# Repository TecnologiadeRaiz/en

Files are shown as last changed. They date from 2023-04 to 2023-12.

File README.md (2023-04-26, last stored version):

# This project is documented with GitBuilding

## What is GitBuilding

GitBuilding is an OpenSource project for documenting hardware projects with minimal
effort, so you can stop writing and GitBuilding. GitBuilding is a python program that
works on Windows, Linux, and MacOS. More information on the GitBuilding project, or how
to install GitBuilding please see the [GitBuilding website](http://gitbuilding.io)

## How do I edit the documentation?

To edit the documentation you do not need to install anything, but you will need to
install something to build the final version of the documentation (such as a website).
The documentation files can be opened in a plain text editor such as Windows Notepad,
Notepad++, gedit, VS Code, etc. GitBuilding also comes with a browser-based editor that
displays has a live display of the final HTML documentation.

If you have ever used [markdown](https://www.markdownguide.org/basic-syntax/) you will
notice that the files you are editing are markdown files. GitBuilding uses an extended
markdown syntax (that we call BuildUp). This allows you to keep track of parts in the
documentation. More detail on the documentation is available on the
[GitBuilding website](https://gitbuilding.io/syntax/). There is also additional
[syntax for configuration](https://gitbuilding.io/syntax/buildconfsyntax), and for
[part libraries](https://gitbuilding.io/syntax/builduplibrary/).

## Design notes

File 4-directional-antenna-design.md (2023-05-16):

<!--
SPDX-FileCopyrightText: 2023 Tecnología de Raíz <tecnologiaderaiz@disroot.org>

SPDX-License-Identifier: CC-BY-NC-4.0
-->

# Directional antenna design

The present design aims to provide how to make a directional MiMo antenna for 5Ghz, capable of achieving a gain of 20dB to 25dB.

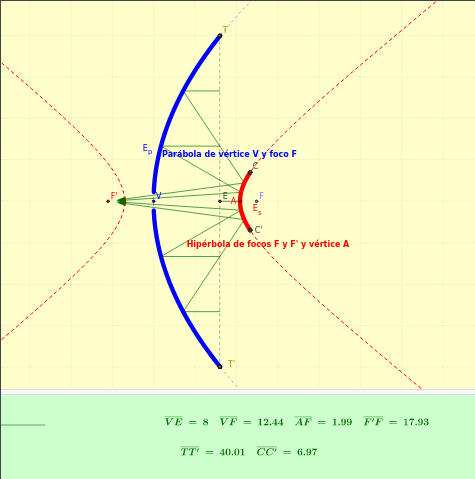
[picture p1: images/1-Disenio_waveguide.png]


In this new iteration of the "Trompebolic" design, we used a 44mm waveguide with a reflector to illuminate the parabolic dish.
We used a 40cm diameter and 8cm high parabolic dish as a mould, calculating the focus at 12.5cm from the centre.

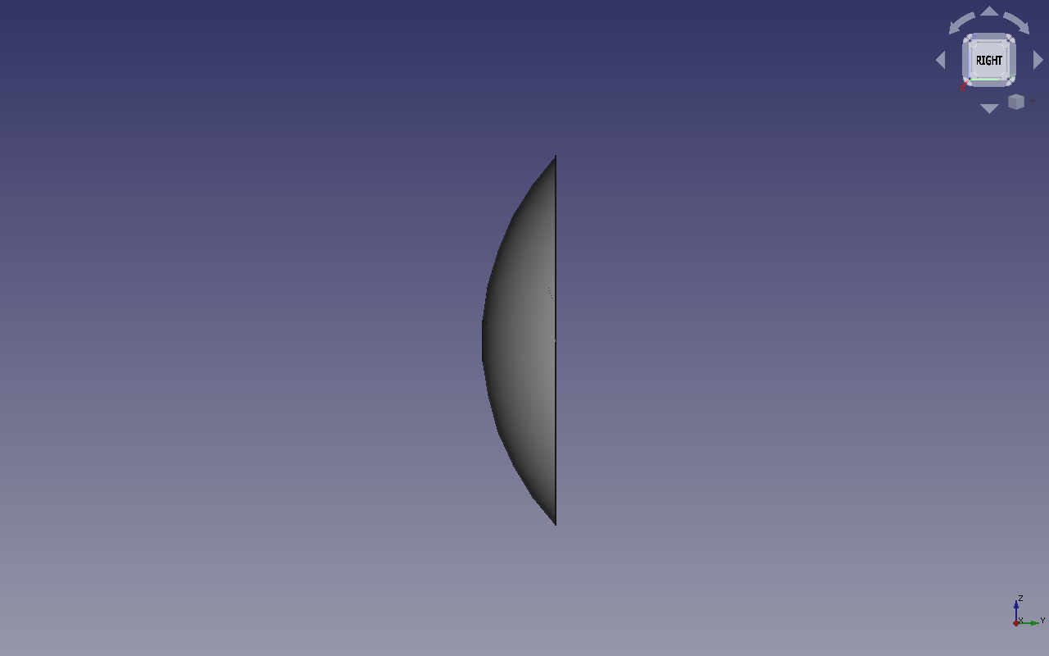
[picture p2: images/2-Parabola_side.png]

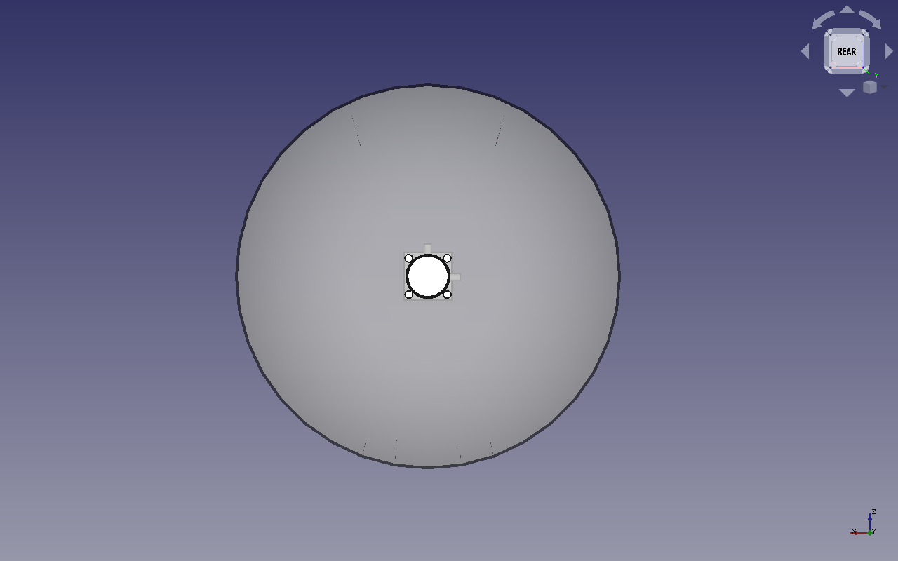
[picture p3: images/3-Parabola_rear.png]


### Reflector.

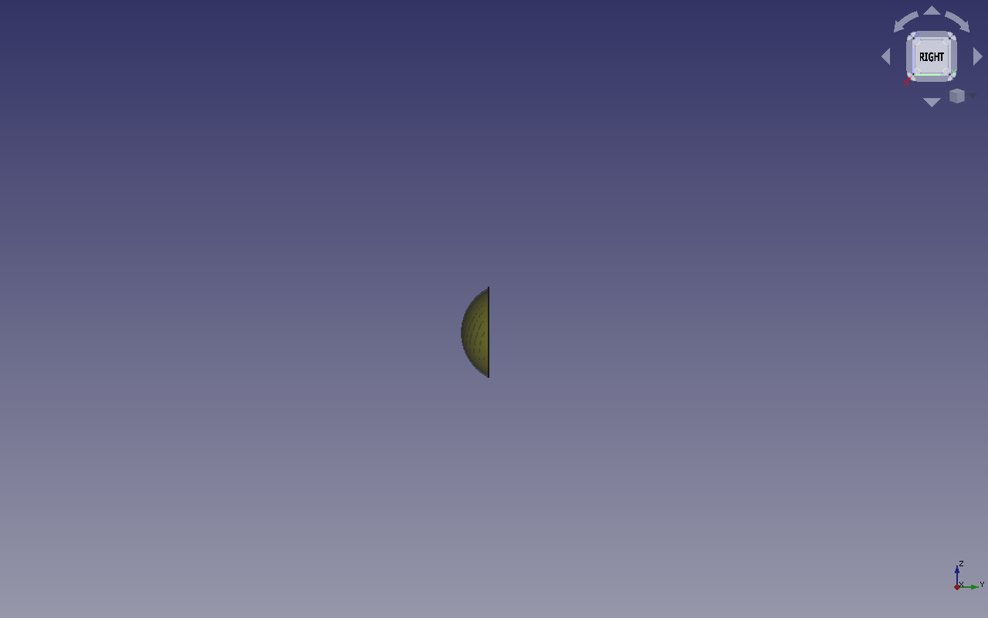
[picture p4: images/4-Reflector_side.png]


### Parabola support and handles.

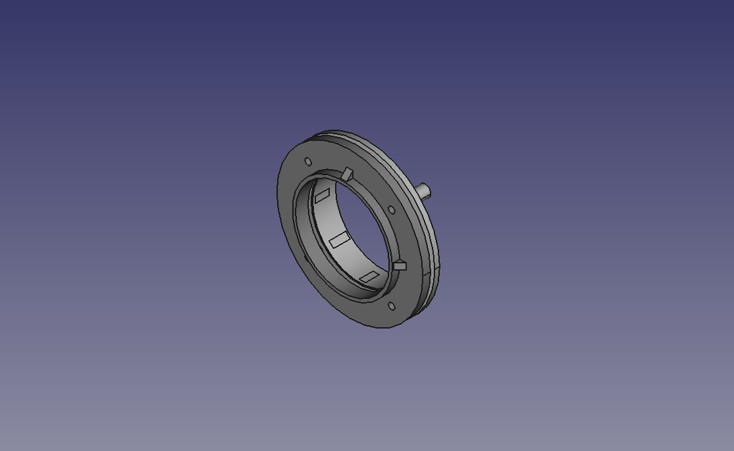
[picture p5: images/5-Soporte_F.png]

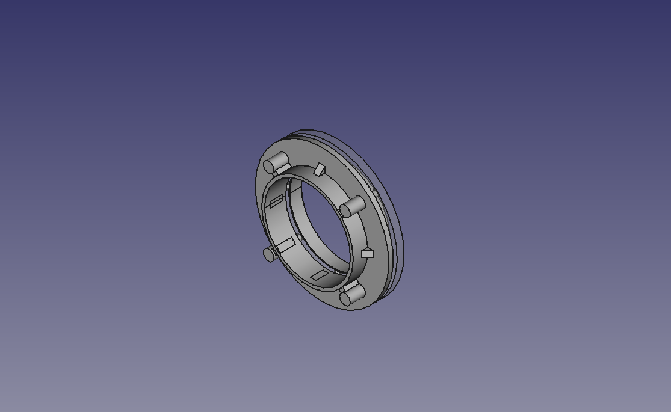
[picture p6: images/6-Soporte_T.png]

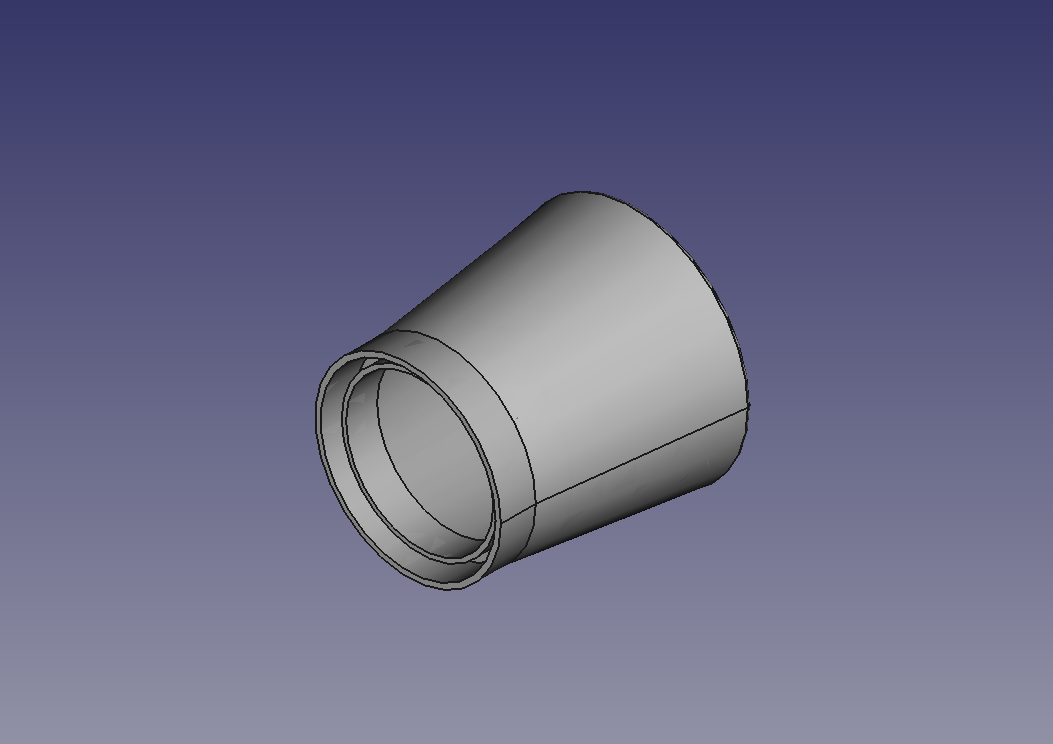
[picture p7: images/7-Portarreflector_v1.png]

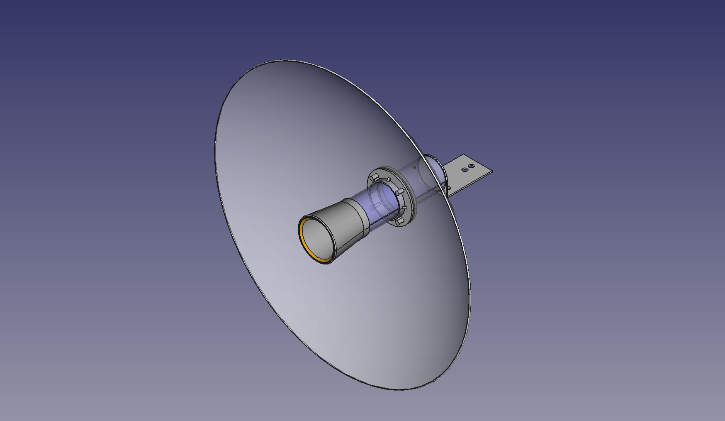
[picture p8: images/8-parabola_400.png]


### Final design.

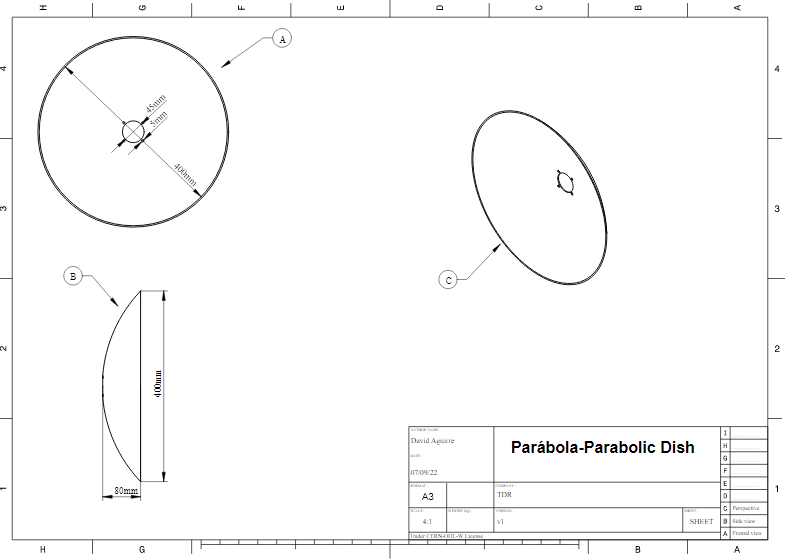
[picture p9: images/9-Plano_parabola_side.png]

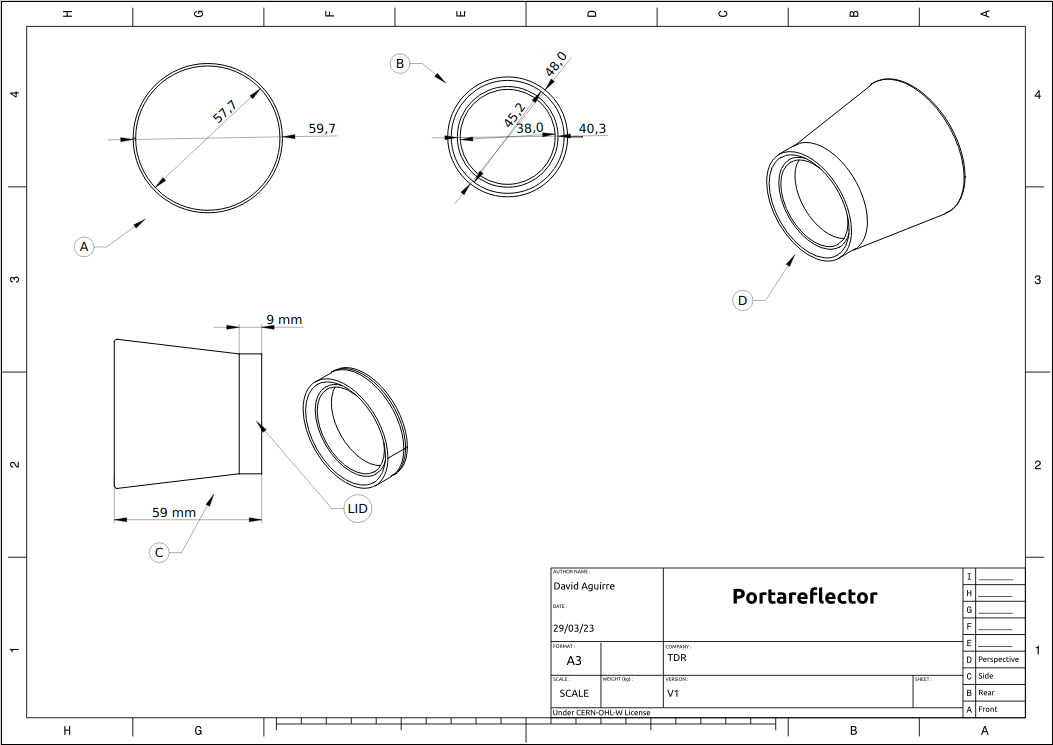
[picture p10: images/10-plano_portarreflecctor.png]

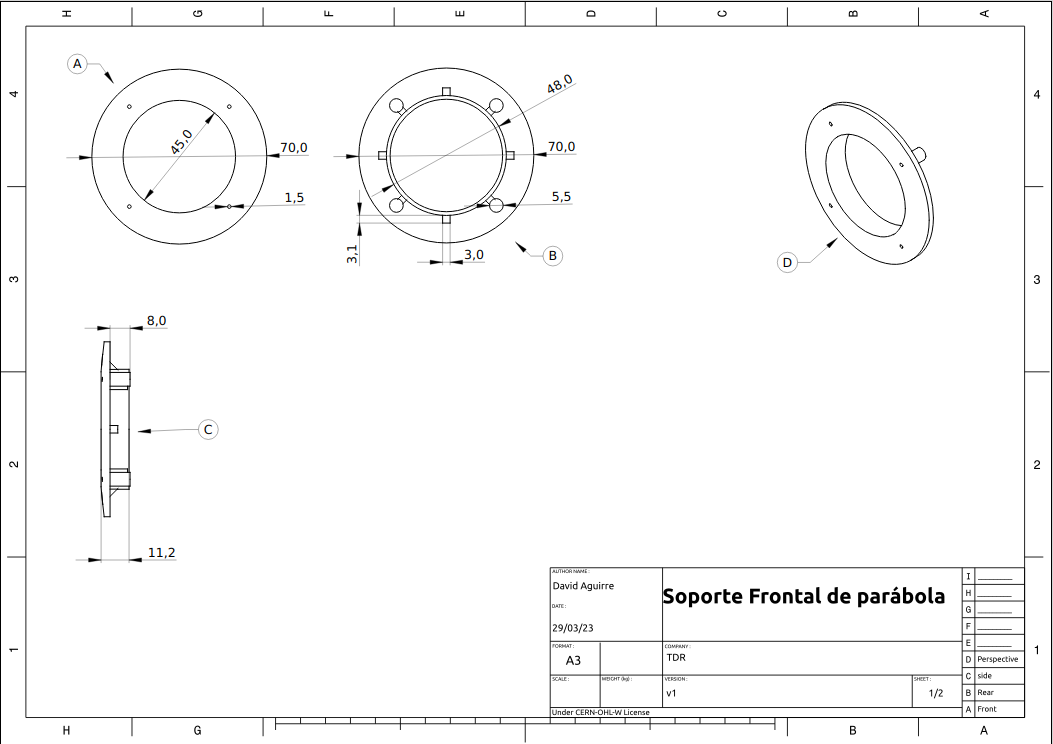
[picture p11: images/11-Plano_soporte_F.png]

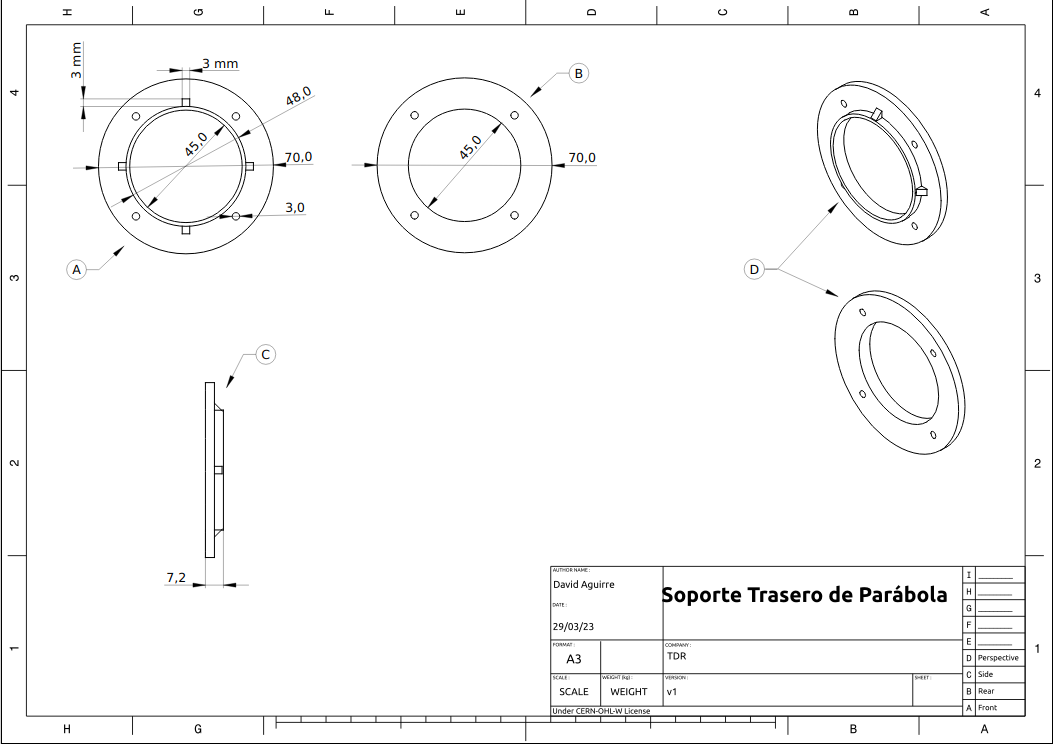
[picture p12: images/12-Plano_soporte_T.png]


___

Logo NLnet: abstract logo of four people seen from above

<p>This project was funded through the <strong> <a href="https://nlnet.nl/useroperated/">User-Operated Internet</a> </strong> fund, a fund established by <a href="https://nlnet.nl">NLnet</a> made possible by financial support from the <a href="https://pkt.cash" rel="nofollow">PKT Community</a> <a href="https://pkt.cash/network-steward" rel="nofollow">The Network Steward</a> and stichting <a href="https://technologycommons.org">Technology Commons Trust</a>.</p> 

<p>En cooperación con <a href="https://altermundi.net/">AlterMundi.</a></p>

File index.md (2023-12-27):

<!--
SPDX-FileCopyrightText: 2023 Tecnología de Raíz <tecnologiaderaiz@disroot.org>

SPDX-License-Identifier: CC-BY-NC-4.0
-->

# Tecnología De Raíz

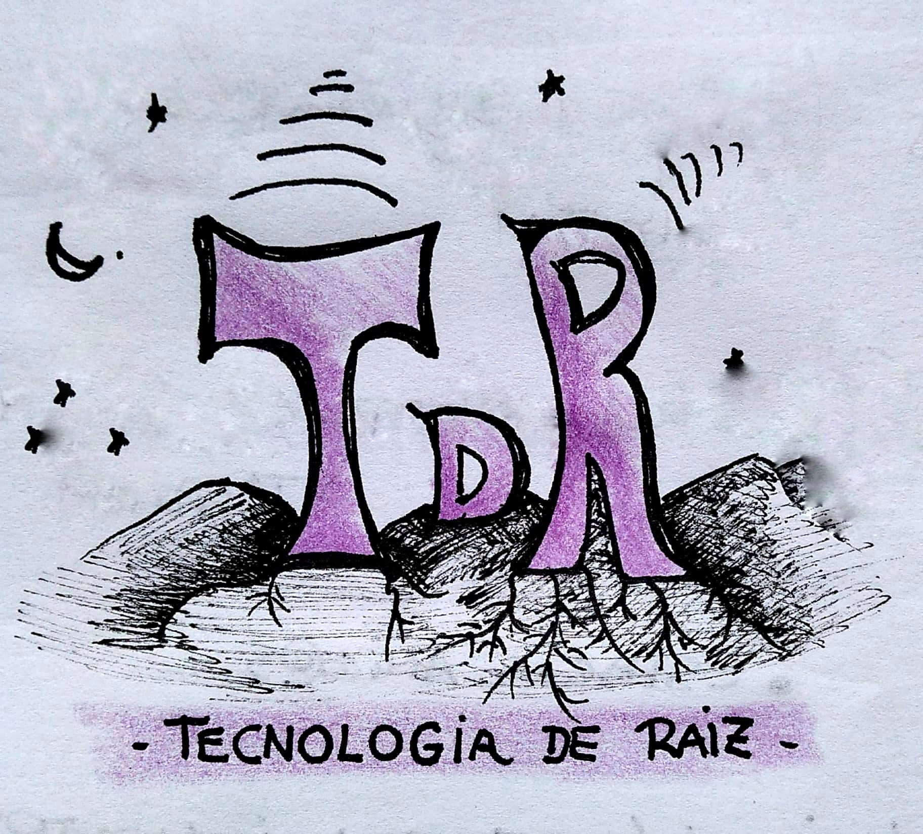
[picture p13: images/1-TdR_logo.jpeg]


## We are TdR

Neighbors of the Ecological Neighborhood "El Montecito" located in Punilla Valley (Córdoba, Argentina)

We formed a study and research group, wherein we created a space to work and study together, and we have sustained it continuously since mid-2019.

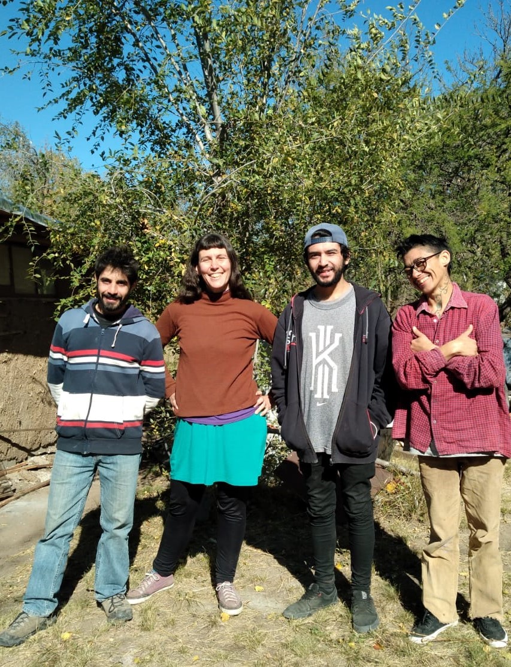
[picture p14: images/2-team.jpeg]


We start from curiosity and interest in sharing information about electricity, electronics, technology and the right to repairs. 
Going that way, the MonteNet network was simultaneously deployed in our neighborhood, and we began to learn about community networks.

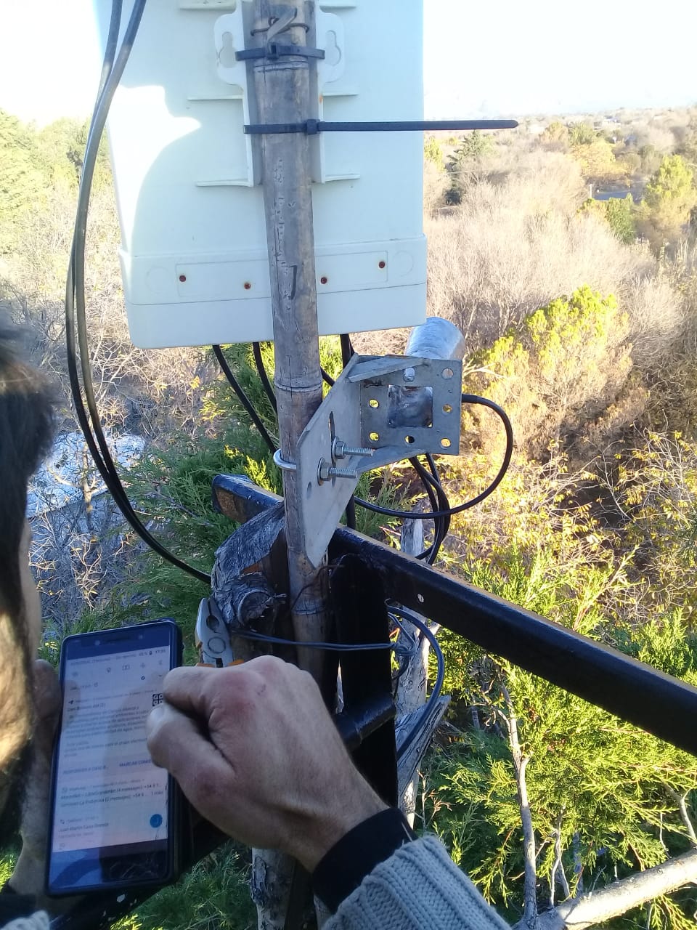
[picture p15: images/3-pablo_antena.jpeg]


We focus our interest on the research and development of antennas.

By forming ourselves as a working group, our search is:

* Generate an antenna prototype that can be easily reproduced.
* Generate a work group with a gender perspective where, through communication, we strengthen our ties and thus build a harmonious work space.
* Develop our enterprise for productive purposes, so that it allows us to generate income.

For this, we use a workshop space with a limited number of tools, which allow us to develop our production, but we would like to be able to improve it, both in terms of construction and adding machines and tools

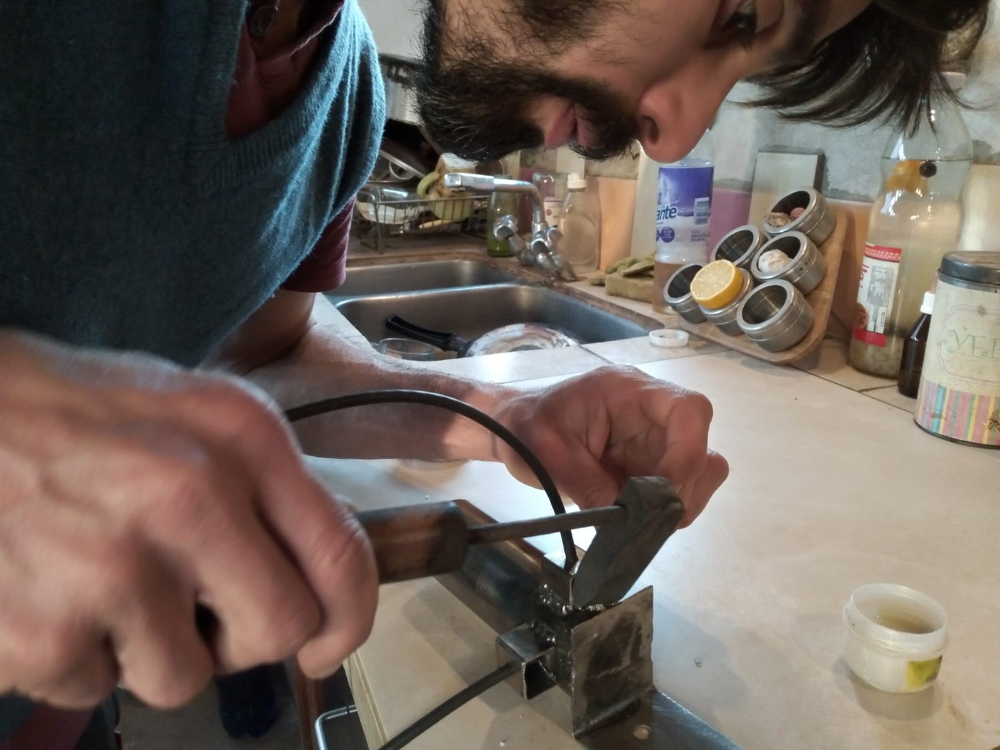
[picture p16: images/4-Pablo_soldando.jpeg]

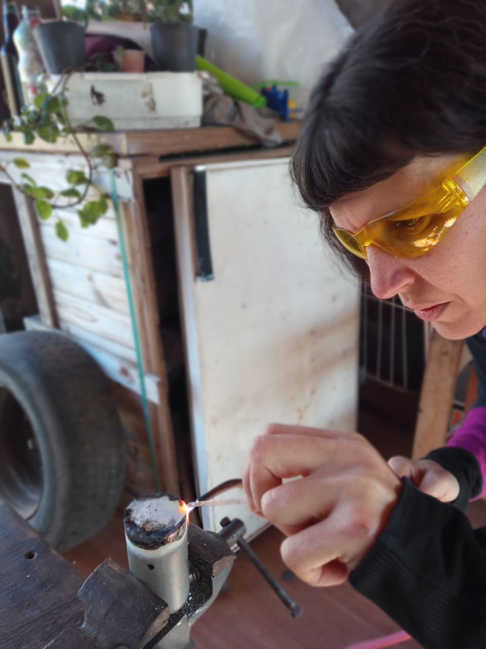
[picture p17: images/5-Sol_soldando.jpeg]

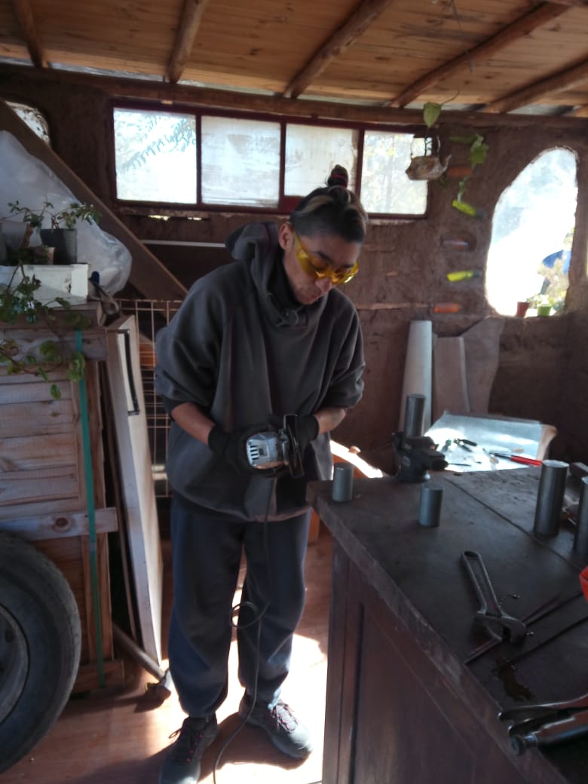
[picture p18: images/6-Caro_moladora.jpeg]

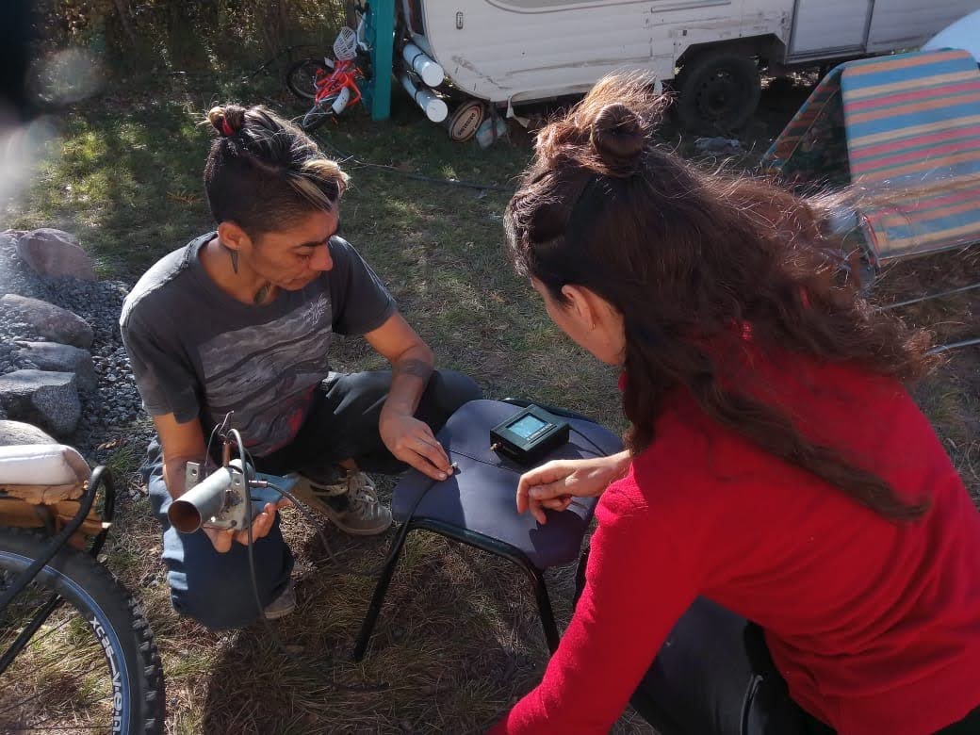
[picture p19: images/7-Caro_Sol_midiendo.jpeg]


We started the research path by building double biquad antennas.

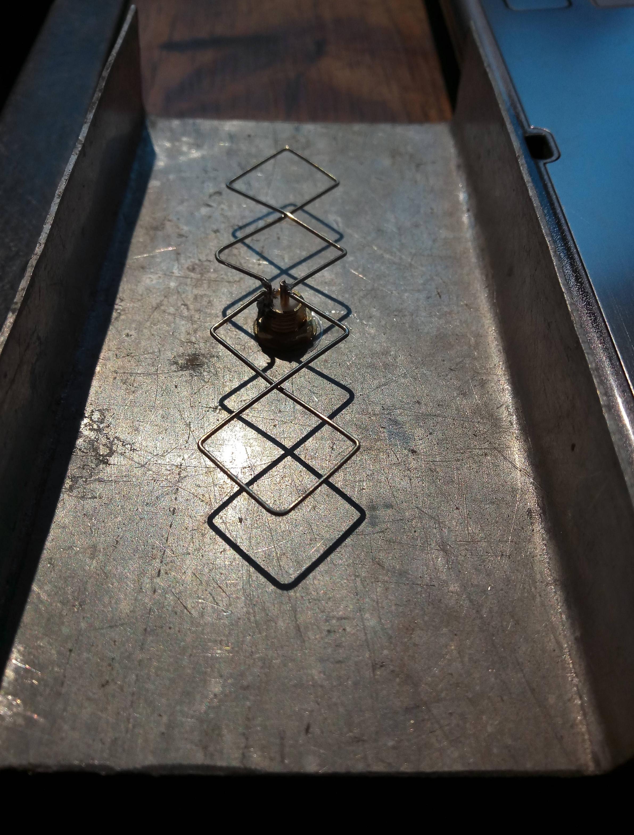
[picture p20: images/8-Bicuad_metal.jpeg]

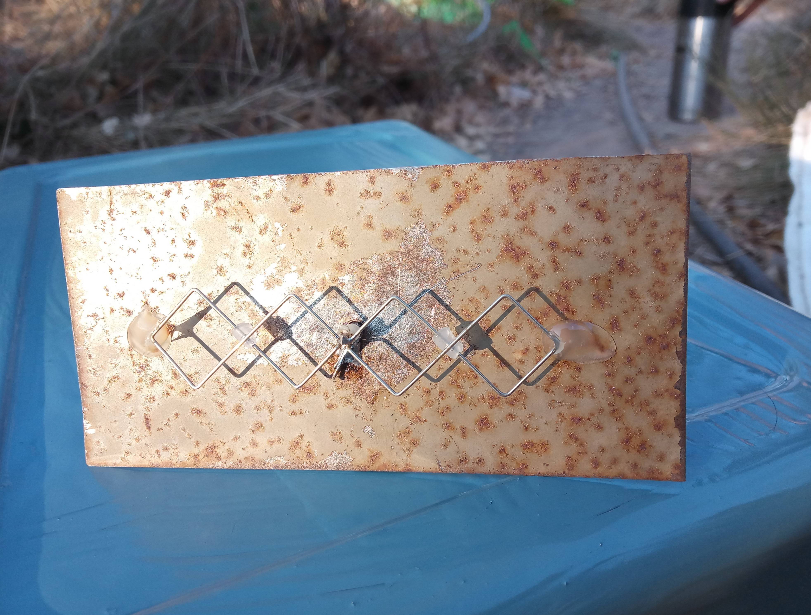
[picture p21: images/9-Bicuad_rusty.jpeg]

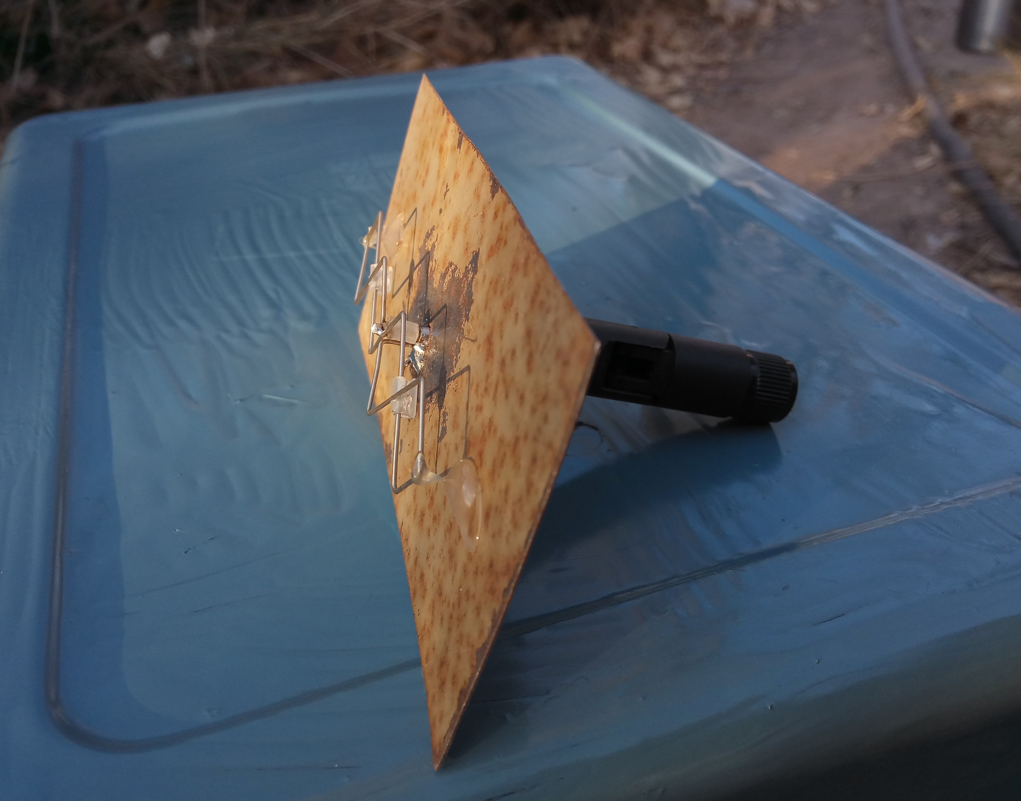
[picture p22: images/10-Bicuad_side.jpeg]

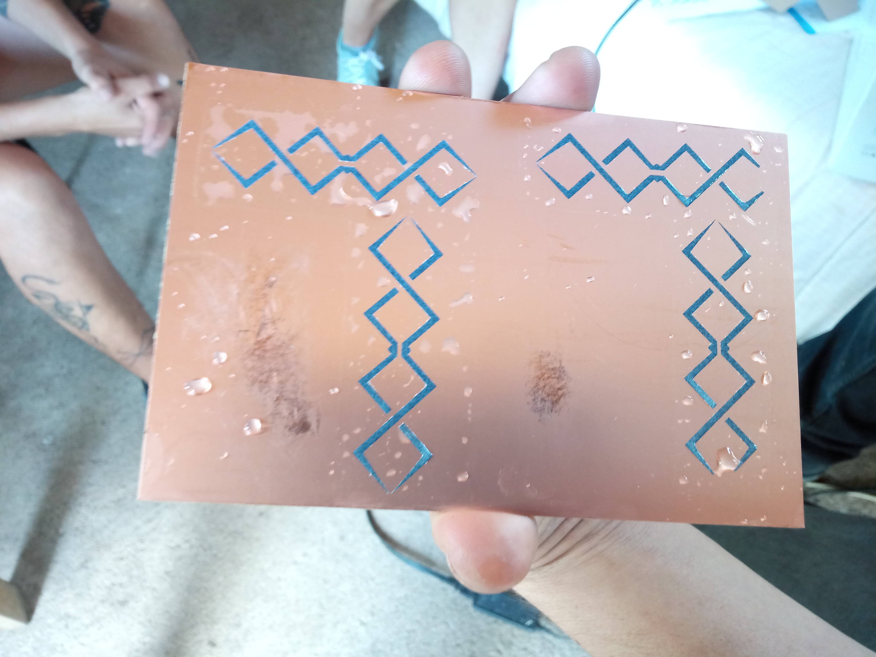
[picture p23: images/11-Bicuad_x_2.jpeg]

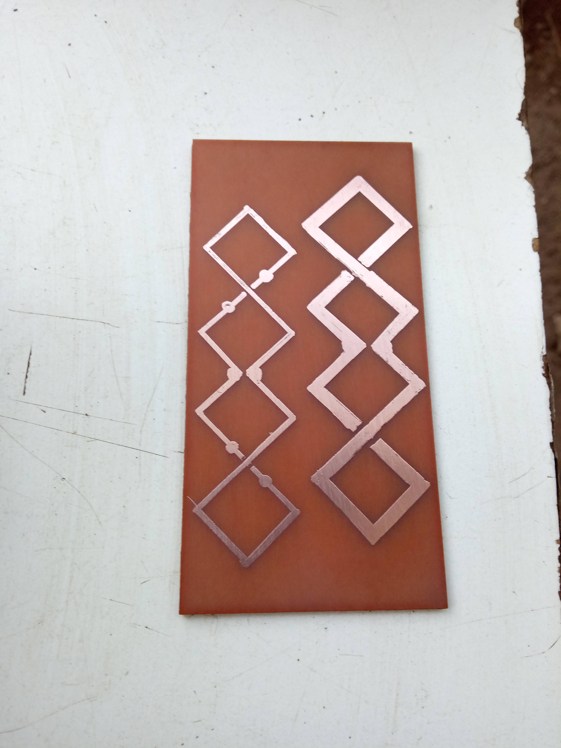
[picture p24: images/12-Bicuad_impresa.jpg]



Some of which are installed in the MonteNet network, helping to improve the link between nodes.



We have built some [waveguides](https://tdr.libre.org.ar/paso-a-paso-sectorial/) for the community networks in our territory, and we are working on a productive enterprise with them, responding to the needs of the networks, trying to create an efficient, low-cost, locally produced product.

### On that path, we encountered some difficulties:

* The tools we have do not allow us much precision, we need to work even more in the workshop space to optimize the work.

* The tests we carried out were measured with a program that was developed for this purpose, but it took us quite a few attempts to adapt it and use it optimally.
 
* The stage for the tests has many variables, in addition to being shared with other people in the community and at height.

### For some time now, we have been working on these tasks:

* Research and production of functional antenna prototypes for community communication networks.

* LibreRouters logistics, reception, testing and shipments nationwide.

*  Review of mails -orders and inquiries about LibreRouters-

* Accompaniment and technical assistance in the MonteNet network.

* Support and promotion of community networks in the area

>i We are motivated to share empowering knowledge that facilitates technological appropriation, and that is why we work on registering our production processes, in order to share them.

---
### Links to LoPALiR project content:
 
* [How to make a design of a sector antenna](2-step-by-step-sectorial.md){step}

* [Waveguide support design](3-waveguide-support.md){step}

* [Directional antenna design](4-directional-antenna-design.md){step}

* [Waveguide and workspace](5-waveguide-and-workspace.md){step}

* [Prototyping](6-waveguide-prototype.md){step}

* [Plastic parts](7-plastic-parts.md){step}

* [Caracterization](Caracterization.md){step}

* [Field test](9-Field-test.md){step}

* [.](downloadable_instructions.md){step}

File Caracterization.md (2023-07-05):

<!--
SPDX-FileCopyrightText: 2023 Tecnología de Raíz <tecnologiaderaiz@disroot.org>

SPDX-License-Identifier: CC-BY-NC-4.0
-->

# Characterization

After the prototyping stage was completed, as planned, we sent one of our models to the [INTI](https://www.argentina.gob.ar/inti) (National Institute of Industrial Technology) to perform a characterization of our sectoral antenna and also of the same antenna converted into a directional one using its accessories.

We are sharing an excerpt of the most relevant data from the report provided by the Communications Department of the INTI.




These images were taken in a semi-anechoic chamber, which allows testing without interference from acoustic or electromagnetic waves.

Through this test we obtained information that allows us to know with precision the characteristics of the antenna.

For both modes of the antenna (sectorial and directional) we requested the measurement of the radiation lobe in two polarizations at 3 specific frequency points:
 5260 MHz, 5550 MHz, 5825 MHz 

These were some of the results of the measurements obtained in the tests.

### Sectorial antenna radiation lobe



### Parameter s11 sector antenna



### Parameter s21 directional antenna



### Directional antenna radiation lobe



### Parameter s11 directional antenna



### Parameter s21 directional antenna



### We share the table of instruments used for the tests.
Instruments used in the measurement of parameters s11 and s21



Instrumentation used to make radiation diagrams


### To summarize:

#### Sectoral antenna characterization:

Maximum gain: 7 dBi

Horizontal beamwidth: 60 degrees

#### Directional antenna characterization with accessories:

Maximum gain: 18 dBi

Horizontal beamwidth: 10 degrees

These results demonstrate a significant improvement in gain and directivity when using the corresponding accessories

Full report in this [link](https://github.com/TecnologiadeRaiz/LoPALiR/blob/main/INFORME%20Waveguide%20INTI.pdf)

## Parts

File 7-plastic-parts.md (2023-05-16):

<!--
SPDX-FileCopyrightText: 2023 Tecnología de Raíz <tecnologiaderaiz@disroot.org>

SPDX-License-Identifier: CC-BY-NC-4.0
-->

# Plastic parts

The possibility of accessing 3D printing as a resource enabled us to create our own molds (tooling) to facilitate the production process, as well as to build inputs for the waveguides.

Initially, the plastic parts arose from the need to replace the plastic lids used as lids with 3D printed plastic lids.

Seeing the potential of 3D printing, we designed a prototype of a portachain to hold the antenna cables, as well as molds to facilitate the drilling of the waveguide pipes.

The current portachain allows us to replace procedures such as welding or resining, shortening production times and costs as well. The process to arrive at these designs and the different previous prototypes are recorded  <a href="6-waveguide-prototype.html">here</a>.
    
This research process involved familiarizing ourselves with the design tools in Freecad and practice with the printer. Currently we are about to access a training course at the UTN (National Technical University) to perfect the prints.

### Lids

Our first <a href="https://github.com/TecnologiadeRaiz/LoPALiR/blob/main/Partes%20plasticas/Tapas/TAPA-v1.FCStd">design</a> allowed us to improve the performance of the antenna, since the plastic strips that we used as a cover interfered with the waveguide signal.

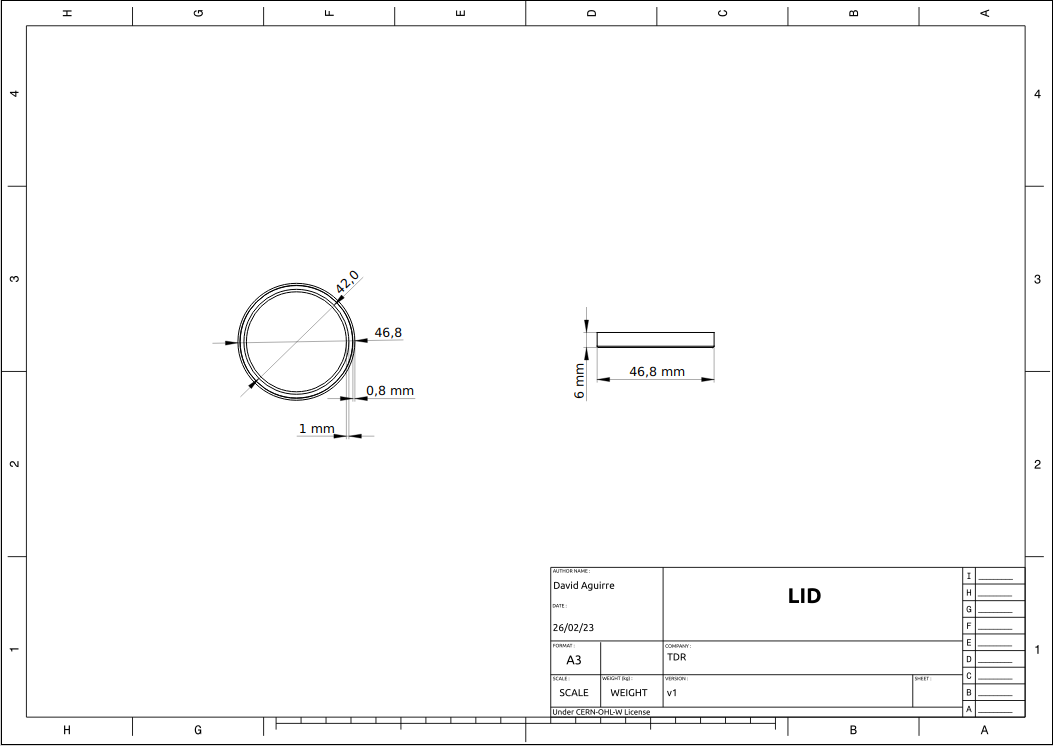
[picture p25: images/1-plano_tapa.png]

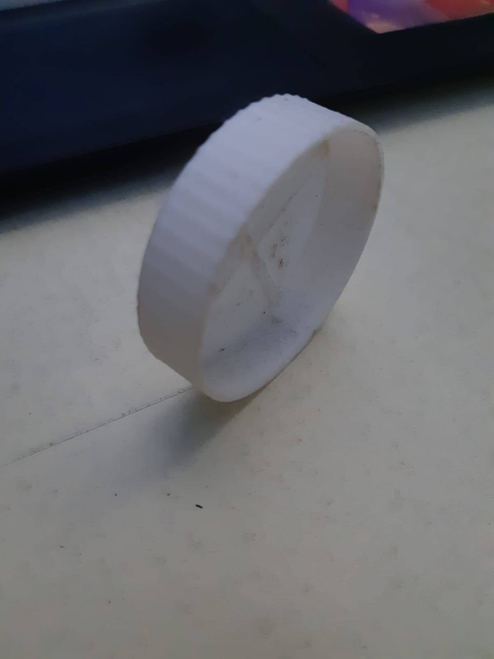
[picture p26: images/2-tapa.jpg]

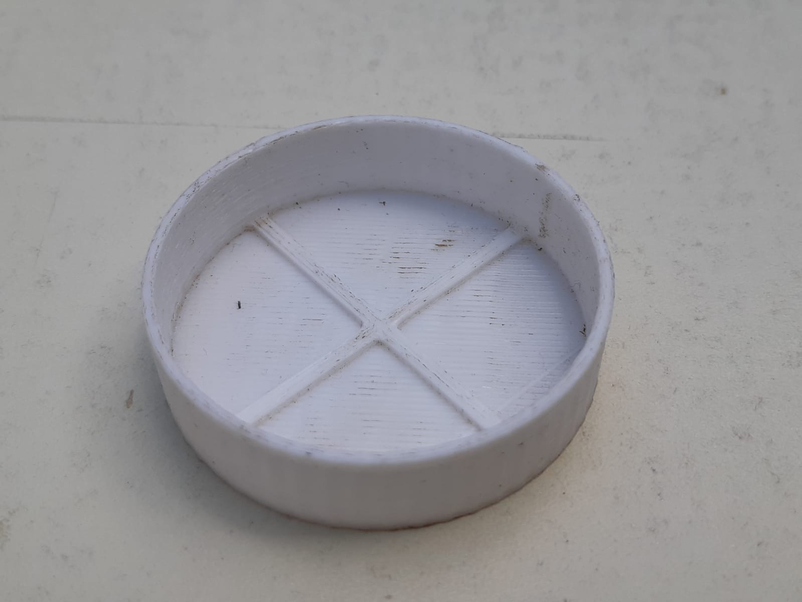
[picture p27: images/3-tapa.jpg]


### Drilling mold   



This <a href="https://github.com/TecnologiadeRaiz/LoPALiR/tree/main/Partes%20plasticas/Molde%20de%20perforacion">design</a> gives us precision when drilling holes in the waveguide, speeding up the production process.

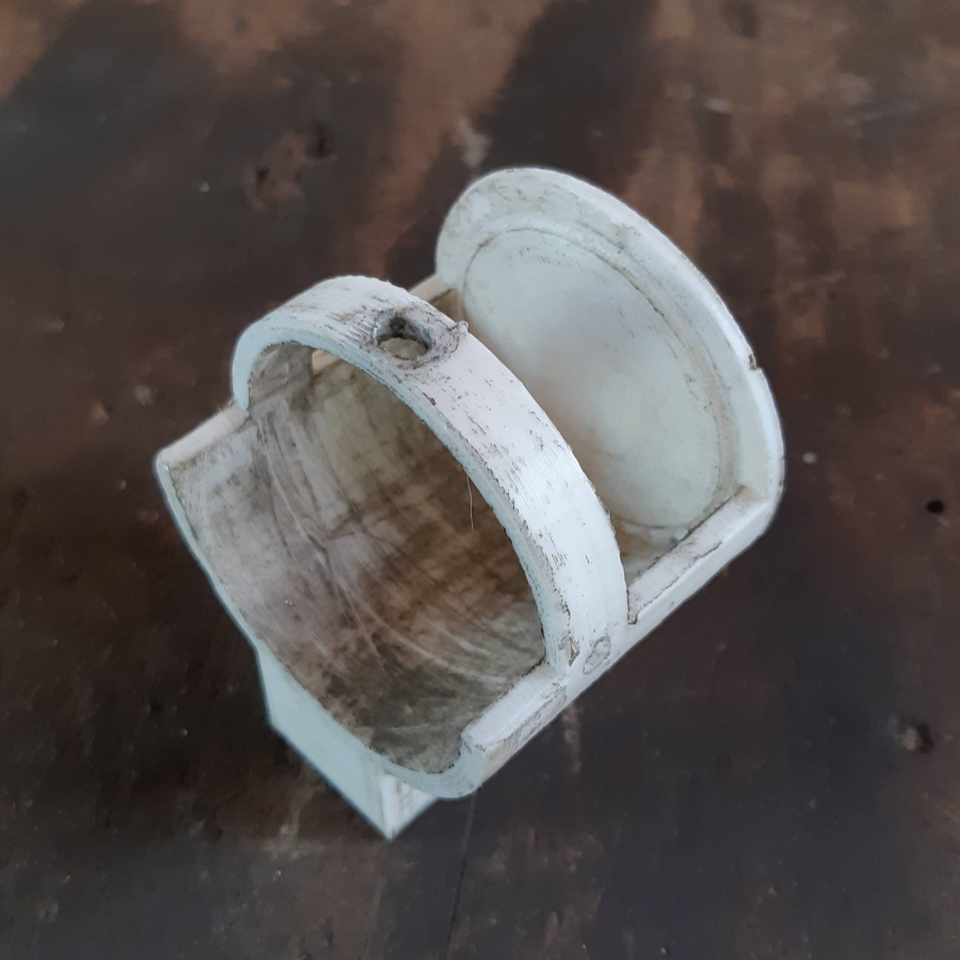
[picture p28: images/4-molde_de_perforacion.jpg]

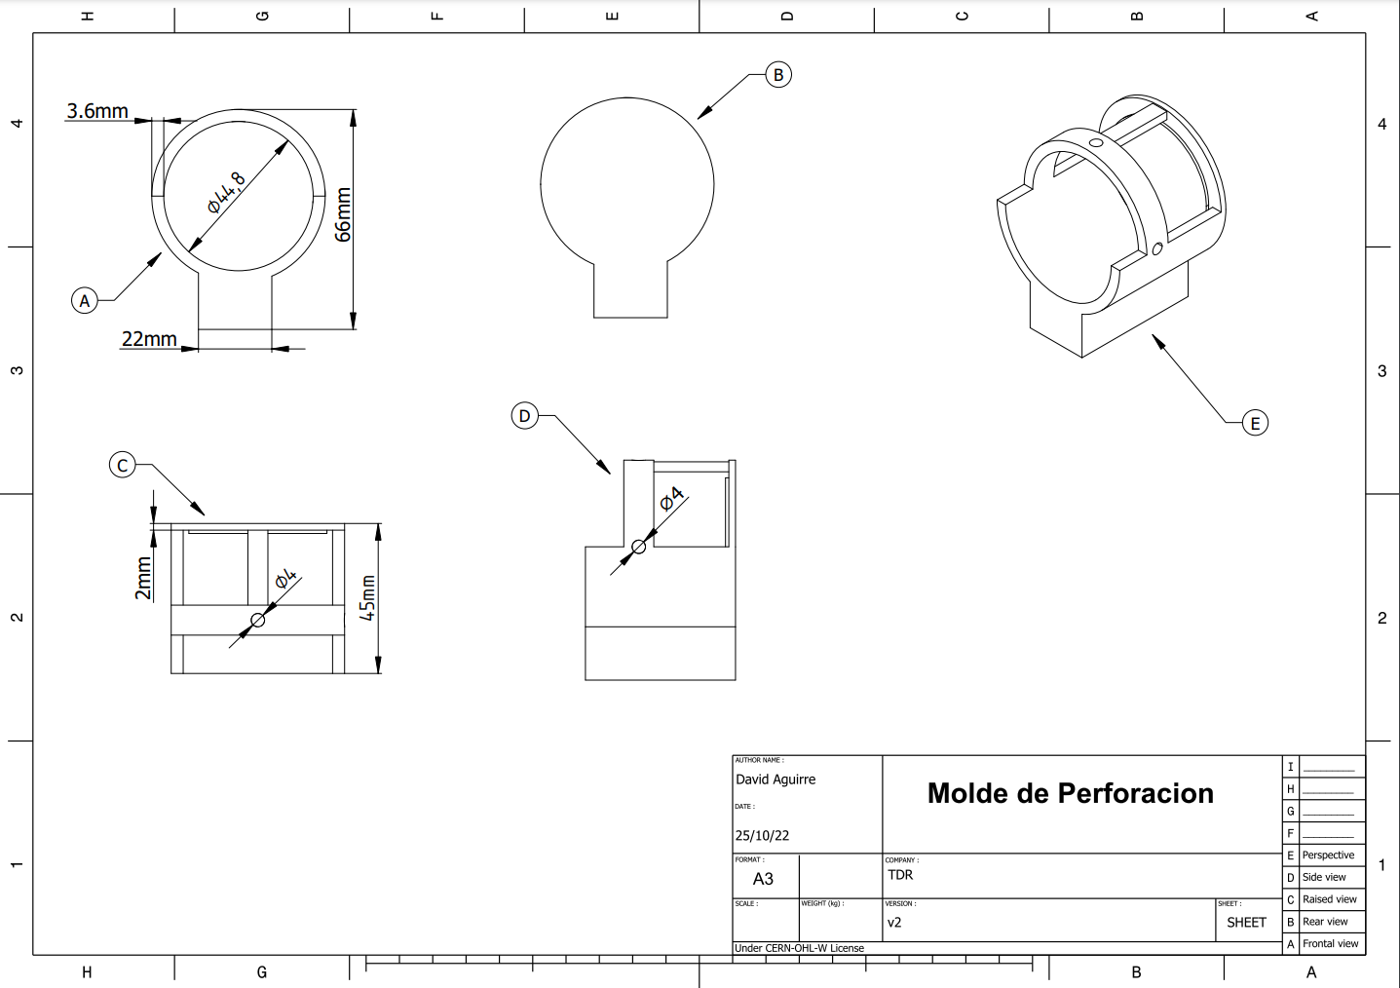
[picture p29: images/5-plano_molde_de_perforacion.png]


### Portachain

The possibility of designing <a href="https://github.com/TecnologiadeRaiz/LoPALiR/tree/main/Partes%20plasticas/PORTACHAIN">these parts</a> allowed us to optimize the way of fastening the cables, which was a challenge in the previous prototypes, meaning higher cost and production times.

The first design was fragile because the material we used, PLA filament, was not suitable for the antennas, as they are exposed to sun, rain and wind.

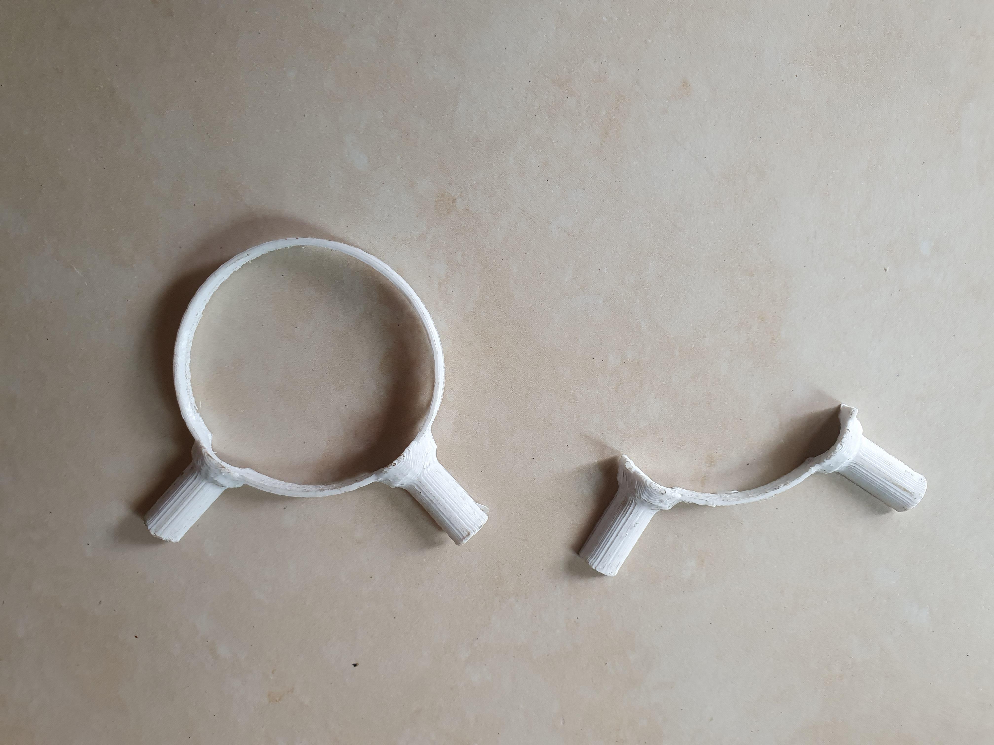
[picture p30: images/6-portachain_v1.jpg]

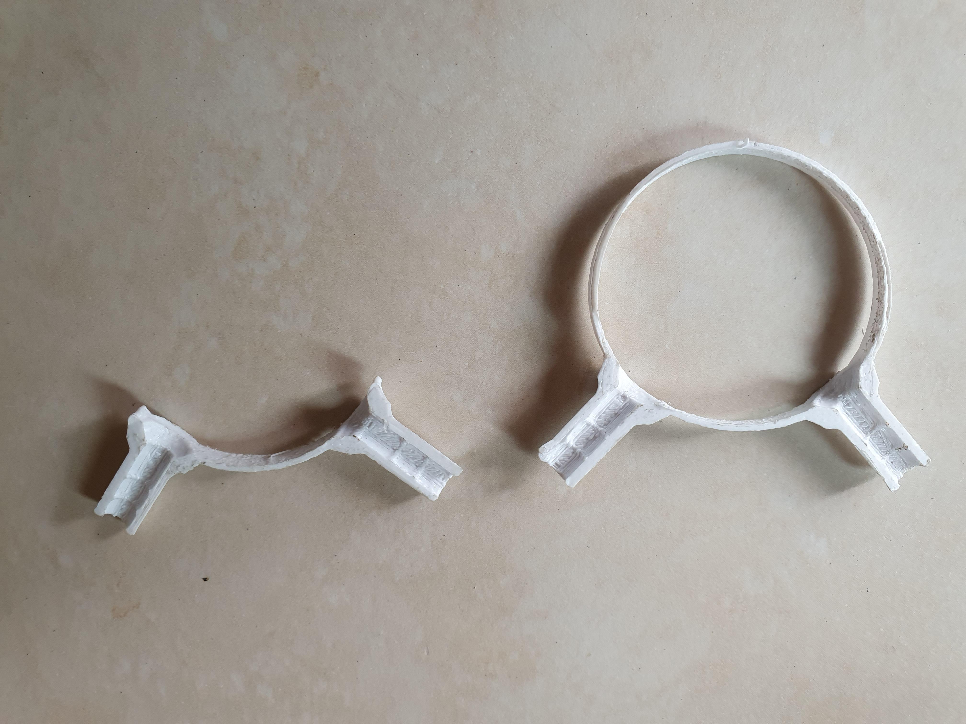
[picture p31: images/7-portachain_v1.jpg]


The second version of the portachain was designed taking into account the increased thickness of the part to give it more solvency, and the material, which was replaced by PETG filament.   

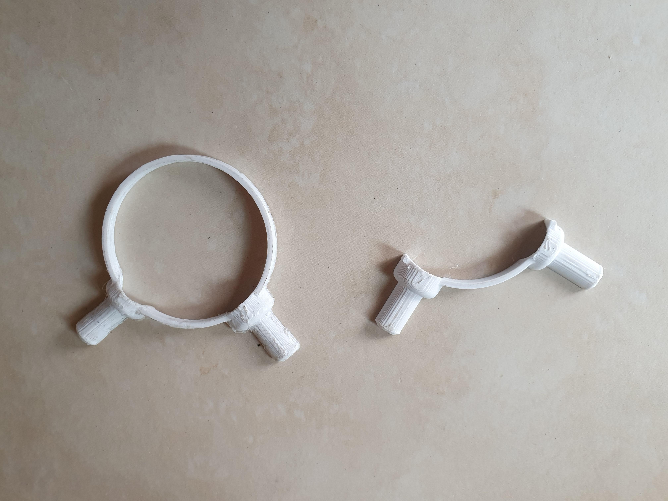
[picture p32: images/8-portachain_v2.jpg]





The first designs did not allow us to hold the cables as expected.

Then we realized that in order to give it a better finish and a better grip, we had to attach a 3/8 crimped aluminum pipe ring to the cable holder, thus providing the expected firmness to hold the cables.







### Paint

To finish the antennas, we use synthetic paint.
Our first experience was to use an automotive paint over a layer of anti-rust paint.
We noticed that it had the following characteristics:

* Being very resistant
* Thicker
* More value

We found it difficult to achieve the right dilution to use it, and we couldn't get a good finish.
That's why we decided to try anti-rust paint which has characteristics such as:

* Converter (works on the rusted parts)
* Prevents rust
* Enamels the parts

Due to these characteristics and the ease of dilution and its covering power, we are currently using this paint as a coating for our models.
For more information about the procedure, <a href="/5-waveguide-and-workspace.html">here.</a>    

### Finished antenna with plastic parts




### couplings for directional antenna design

We have developed several complementary parts to the waveguide, in order to increase the final directionality.
The latest tests confirm that approximately 13dB of gain is achieved in one direction.

Parabola brackets allow the addition of the 16 inch secondary reflector to the waveguide. The nosepiece also covers the inside of the tube and holds the primary reflector in the focal zone of the parabola.
The actual nose takes 5 hours to print, in total the necessary parts take almost 8 hours to print.





___
Logo NLnet: abstract logo of four people seen from above

<p>This project was funded through the <strong> <a href="https://nlnet.nl/useroperated/">User-Operated Internet</a> </strong> fund, a fund established by <a href="https://nlnet.nl">NLnet</a> made possible by financial support from the <a href="https://pkt.cash" rel="nofollow">PKT Community</a> <a href="https://pkt.cash/network-steward" rel="nofollow">The Network Steward</a> and stichting <a href="https://technologycommons.org">Technology Commons Trust</a>.</p> 

<p>Saludamos a les amigues de <a href="https://altermundi.net/">AlterMundi.</a></p>

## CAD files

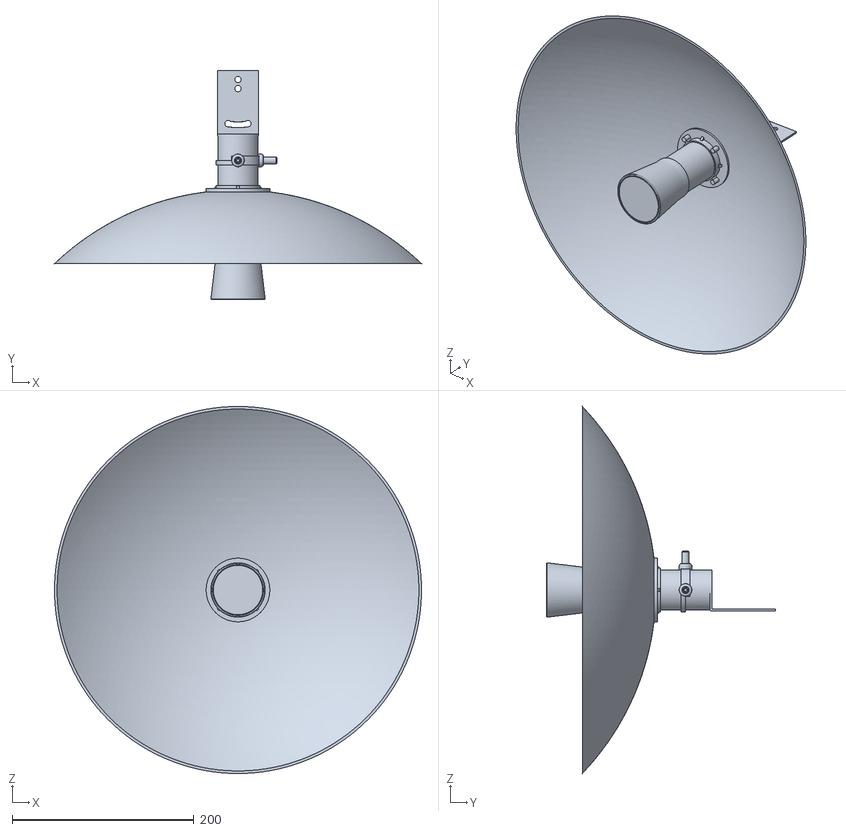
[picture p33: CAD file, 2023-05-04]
models/waveguide-accesorios.stl
403.6 x 252.0 x 403.7

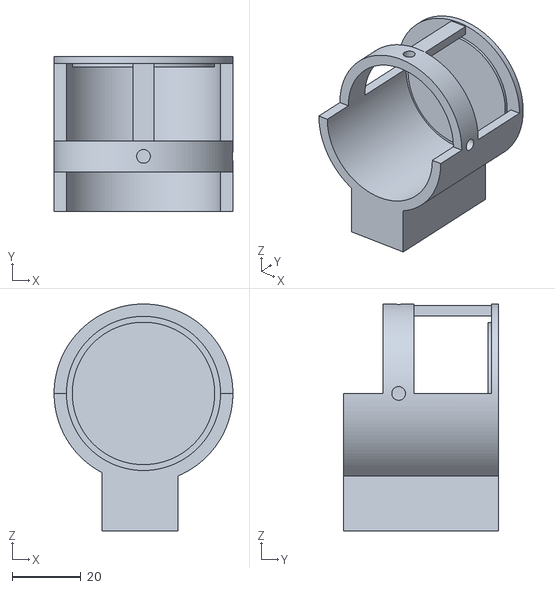
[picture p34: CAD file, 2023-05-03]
models/MOLDEDEPERFORACIONGUIADEONDAS-v2.stl
52.0 x 45.0 x 66.0

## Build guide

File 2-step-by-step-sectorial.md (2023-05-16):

<!--
SPDX-FileCopyrightText: 2023 Tecnología de Raíz <tecnologiaderaiz@disroot.org>

SPDX-License-Identifier: CC-BY-NC-4.0
-->

#Sector antenna

## How to make the design of your sector antenna

We thank NlNet and Altermundi for making this project possible. 

From our reality, we try to create solutions for the development of Hardware in the territories, in an accessible way.

In the search for an antenna design with optimal gain, easily replicable , we return to the research work that AlterMundi began and sustained to estimate dimensions of the antenna, using a [Waveguide calculator](https://github.com/TecnologiadeRaiz/LoPALiR/blob/6cfcefe5b7c623523bdbc38a3de3d6f52c728e81/circular_waveguide_tuneado.ods), adapted for 5.8 GHz by Nicolás Echaniz

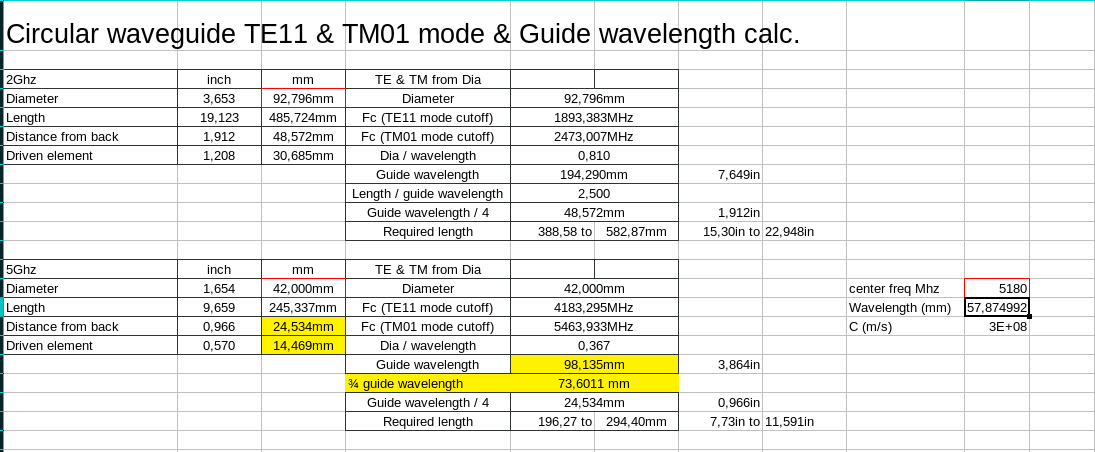
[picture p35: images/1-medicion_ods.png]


This is the foundation on which we build our production experiences and continue to expand research at TDR.

We work with a free drawing software program for the design of the antennas.

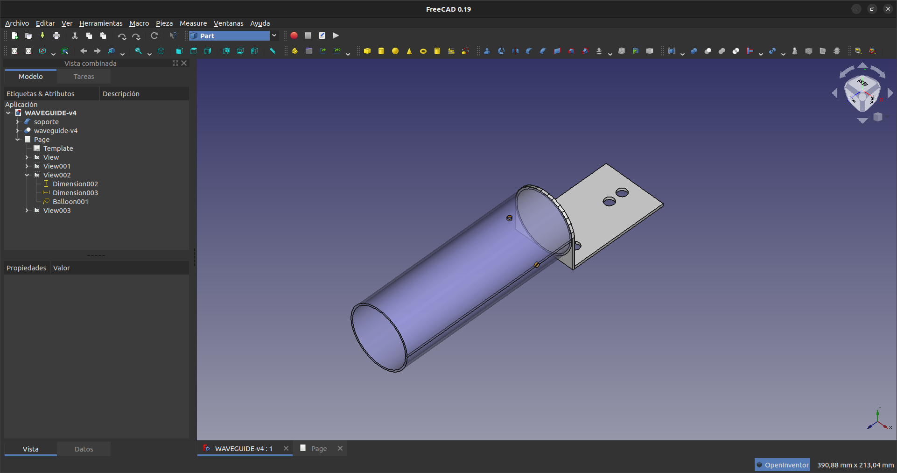
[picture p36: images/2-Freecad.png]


These are the results using [FreeCAD](https://www.freecadweb.org/downloads.php?lang=es_ES)

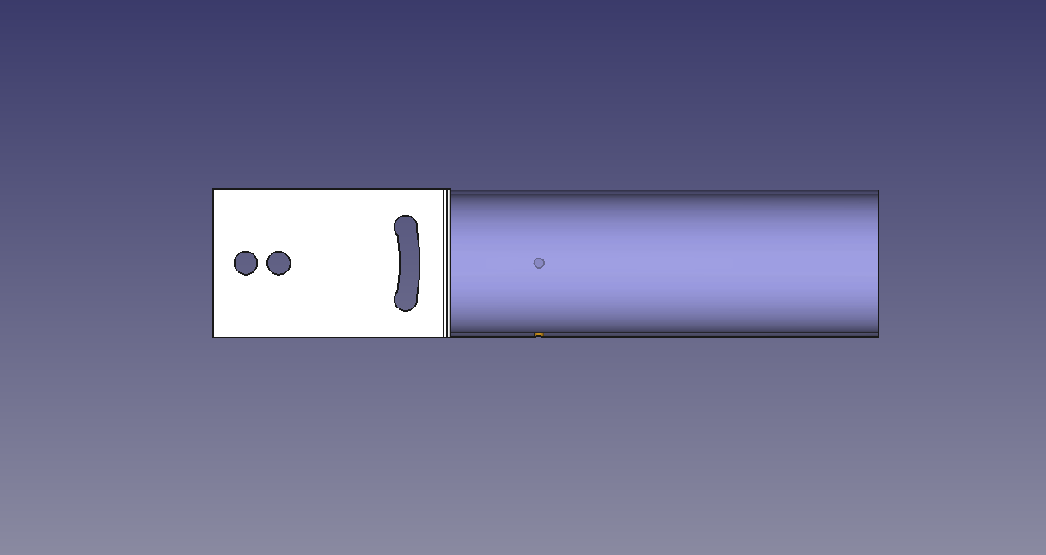
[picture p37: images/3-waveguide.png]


Waveguide and support.

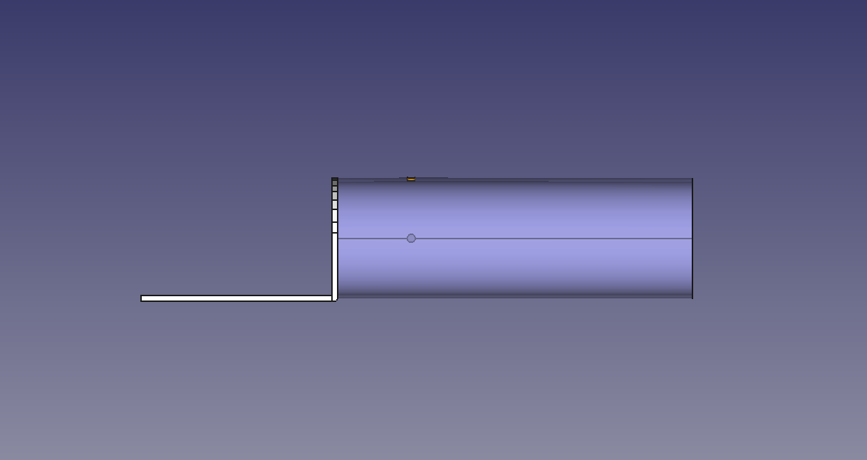
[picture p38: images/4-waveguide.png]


As illuminator we use for each chain, a 11.7mm spike of 95/30 coaxial cable from Indeca and a RP-SMA Male connector at the other end.

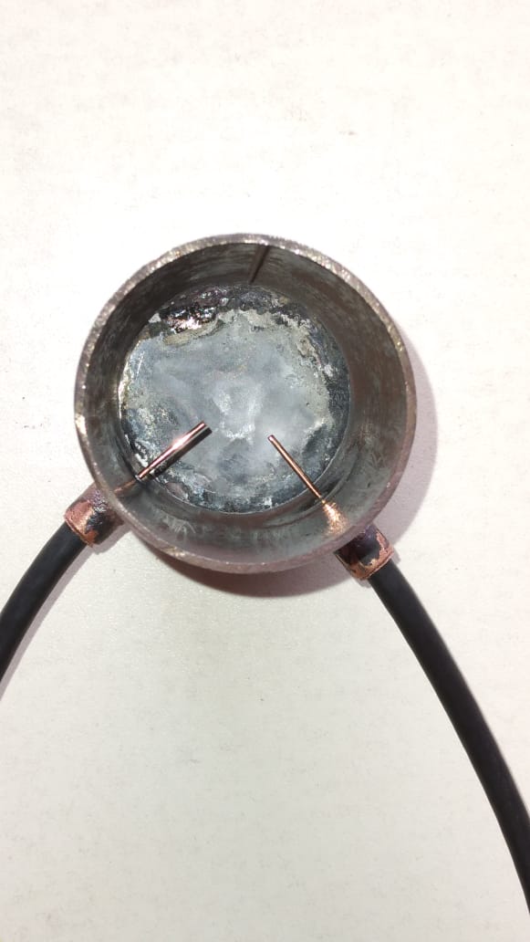
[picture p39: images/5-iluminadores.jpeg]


We provide the plans to build these antennas.

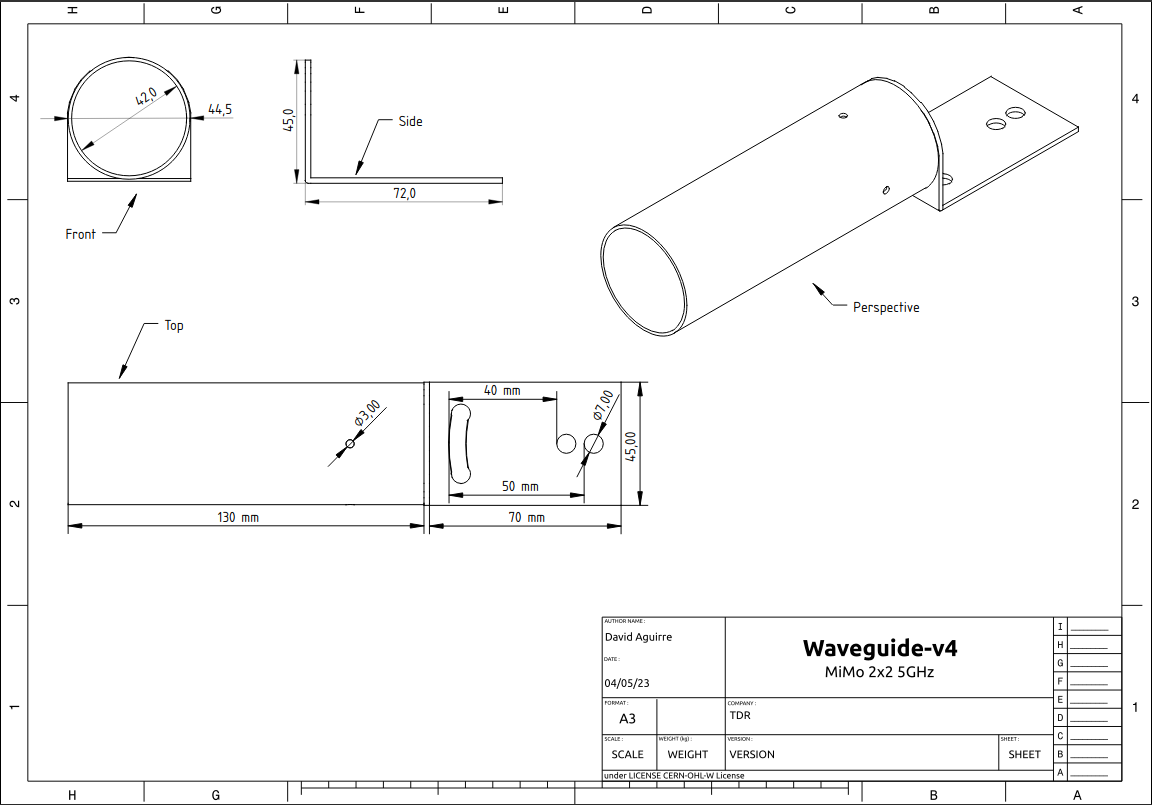
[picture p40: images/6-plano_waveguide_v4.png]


Files in: <a href="https://github.com/TecnologiadeRaiz/LoPALiR">LoPALiR</a>

Logo NLnet: abstract logo of four people seen from above

<p>This project was funded through the <strong> <a href="https://nlnet.nl/useroperated/">User-Operated Internet</a> </strong> fund, a fund established by <a href="https://nlnet.nl">NLnet</a> made possible by financial support from the <a href="https://pkt.cash" rel="nofollow">PKT Community</a> <a href="https://pkt.cash/network-steward" rel="nofollow">The Network Steward</a> and stichting <a href="https://technologycommons.org">Technology Commons Trust</a>.</p> 

<p>En cooperación con <a href="https://altermundi.net/">AlterMundi.</a></p>

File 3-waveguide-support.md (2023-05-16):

<!--
SPDX-FileCopyrightText: 2023 Tecnología de Raíz <tecnologiaderaiz@disroot.org>

SPDX-License-Identifier: CC-BY-NC-4.0
-->

# Waveguide support design

In the research to obtain a support design, we considered:

- Lightweight.
- As few materials as possible.
- That it has the versatility to be able to adapt to smaller or larger pipes.
- The material used should be durable and compatible with the antenna material.
- That it is easy to reproduce.

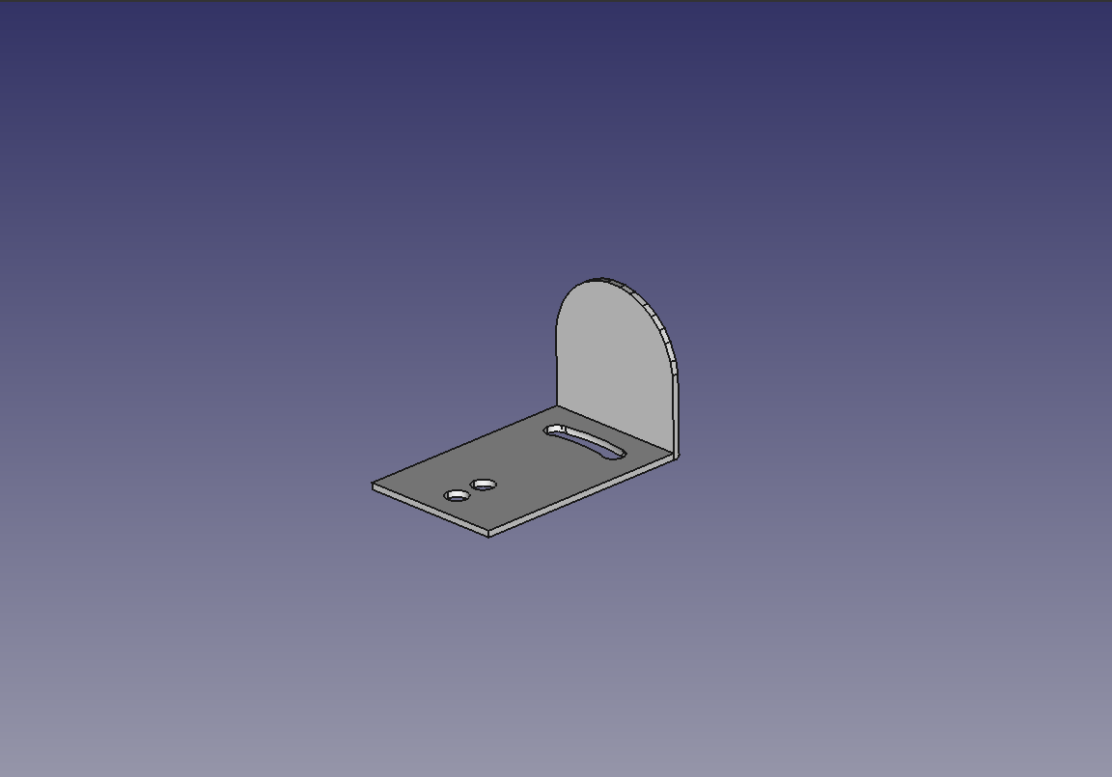
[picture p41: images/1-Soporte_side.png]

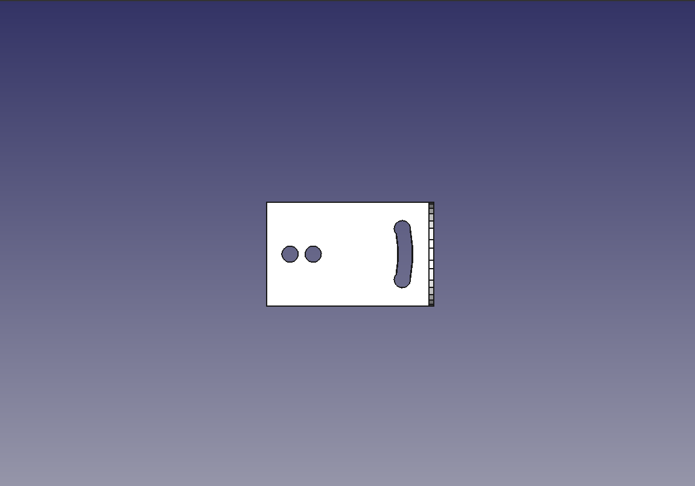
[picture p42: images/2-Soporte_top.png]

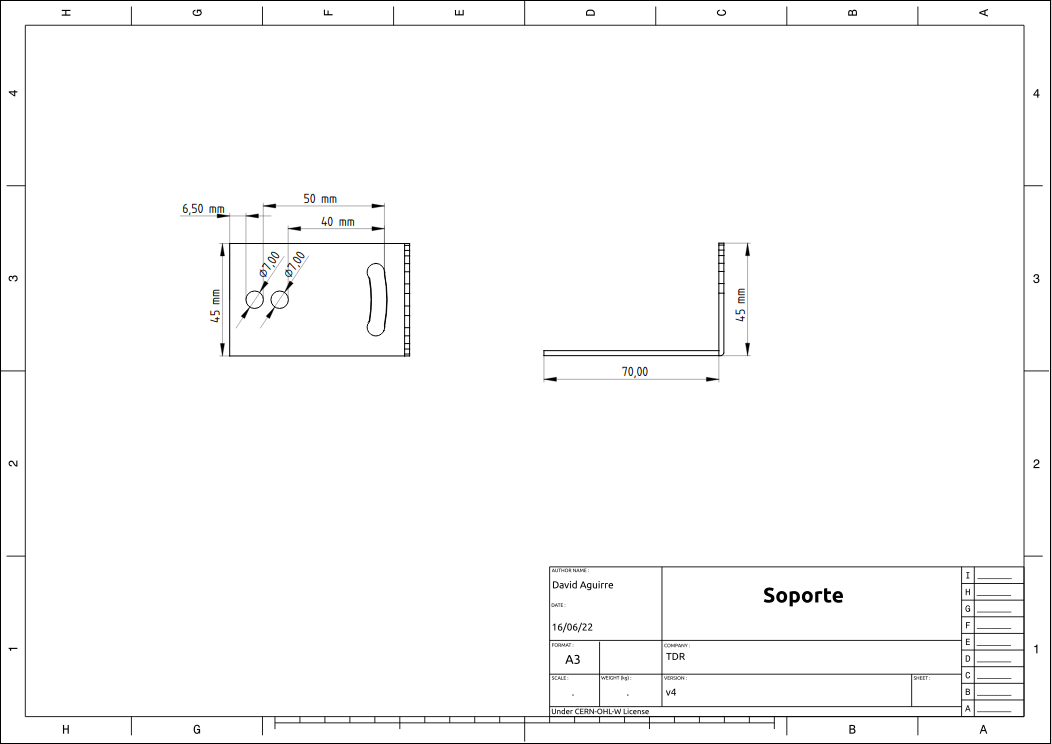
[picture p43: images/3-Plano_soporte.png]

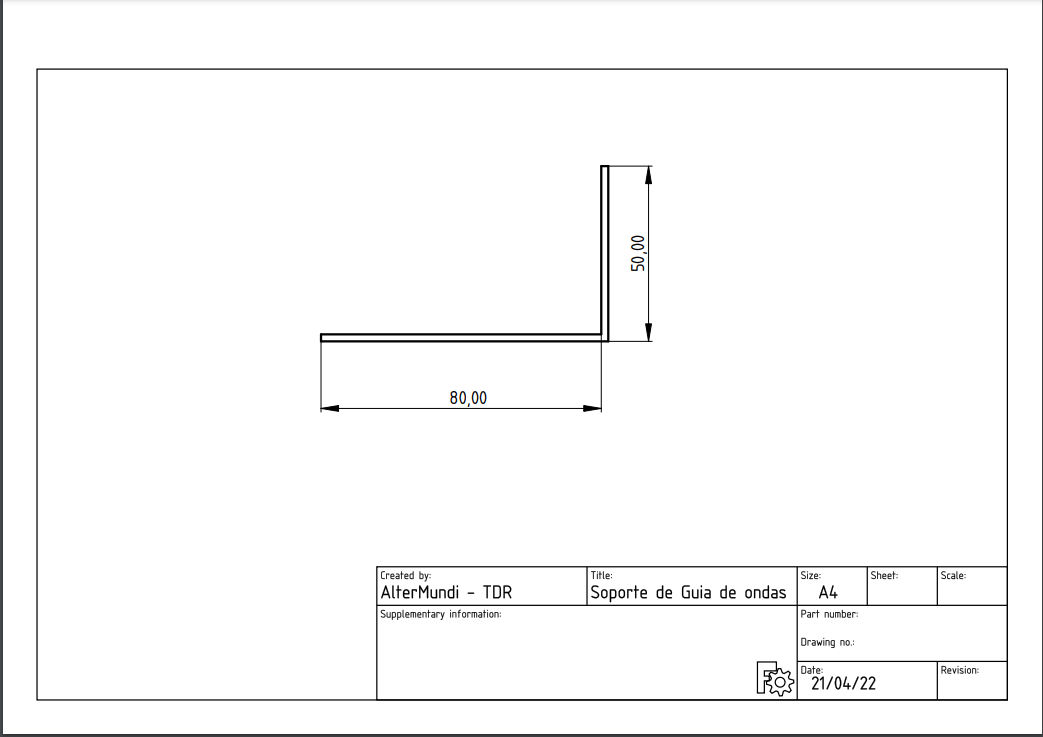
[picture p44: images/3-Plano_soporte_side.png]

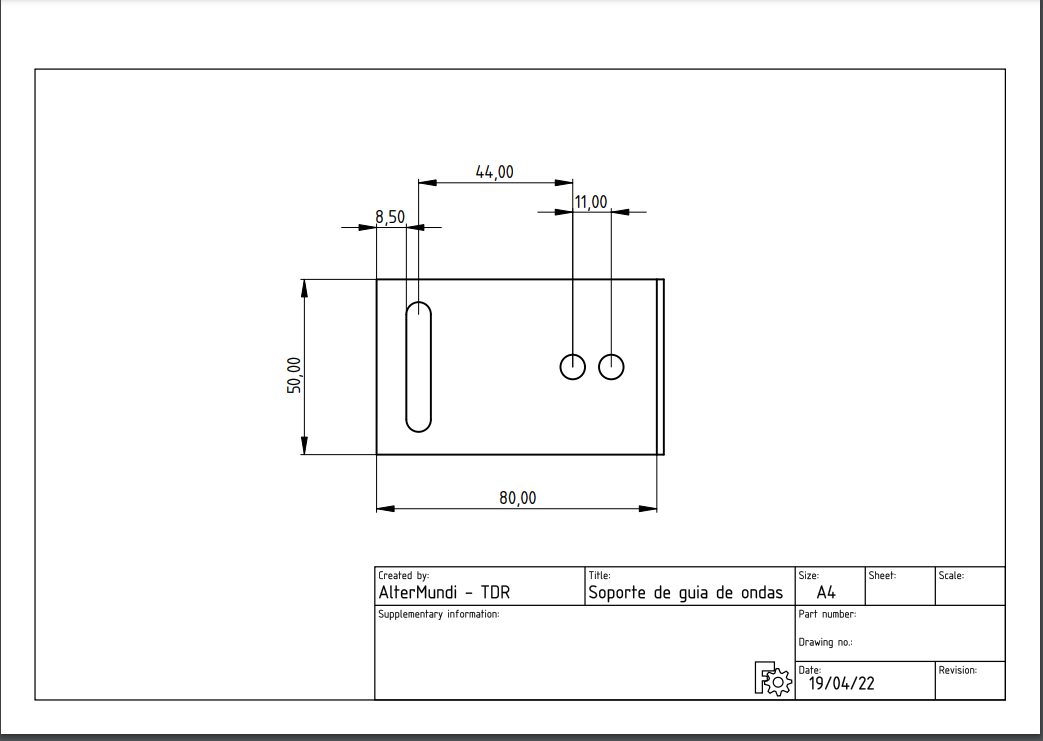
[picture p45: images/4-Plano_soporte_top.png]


Logo NLnet: abstract logo of four people seen from above

<p>This project was funded through the <strong> <a href="https://nlnet.nl/useroperated/">User-Operated Internet</a> </strong> fund, a fund established by <a href="https://nlnet.nl">NLnet</a> made possible by financial support from the <a href="https://pkt.cash" rel="nofollow">PKT Community</a> <a href="https://pkt.cash/network-steward" rel="nofollow">The Network Steward</a> and stichting <a href="https://technologycommons.org">Technology Commons Trust</a>.</p> 

<p>En cooperacion con <a href="https://altermundi.net/">AlterMundi.</a></p>

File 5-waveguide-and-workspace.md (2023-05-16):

<!--
SPDX-FileCopyrightText: 2023 Tecnología de Raíz <tecnologiaderaiz@disroot.org>

SPDX-License-Identifier: CC-BY-NC-4.0
-->

# Workspace description

The physical space in which we work is a 3.5m x 4m room, where we have two work tables:    

* One where we preparate the pipes and metal brackets.
* Another one where we have the device that holds the wires for welding.

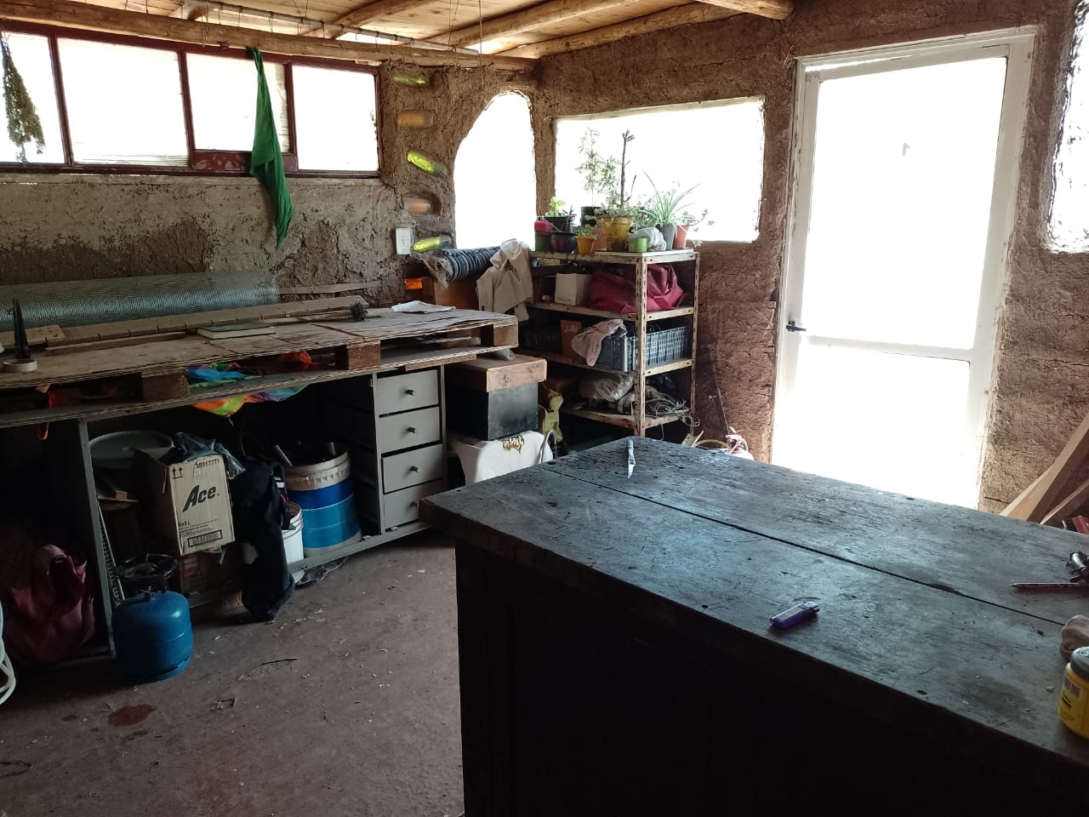
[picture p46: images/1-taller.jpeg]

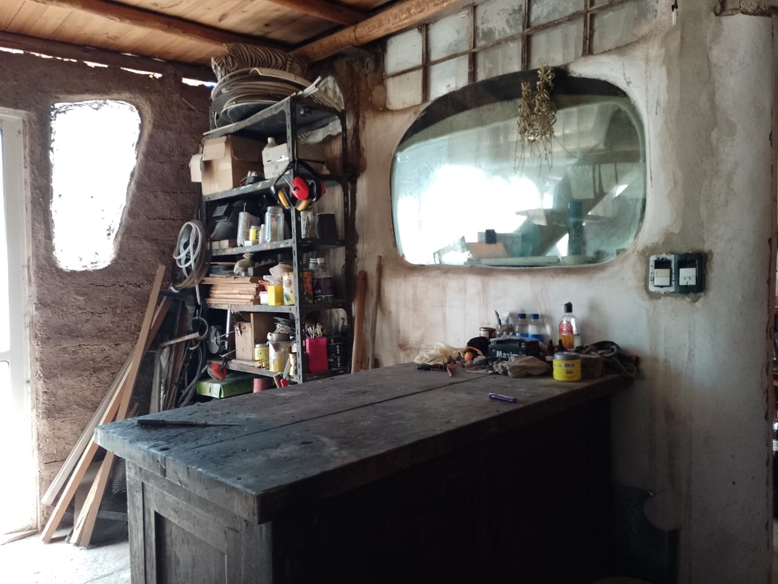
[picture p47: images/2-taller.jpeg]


## Personal protective equipment:

* Hearing protectors
* Gloves
* Goggles
* Masks
* Work clothes

## Production process with advanced materials and tools

## Mark Metal Brackets

#### Workspace:

For this process we use a table and a wooden block that helps us to make the marking with a custom-made template and then drill the  <a href="https://github.com/TecnologiadeRaiz/LoPALiR/blob/main/Plano%20Soporte-v3.svg">metal brackets.</a>

#### For this process we need:    

* Firm table
* Wooden block
* Perforation template
* 2mm thick metal sheet of 50mm x 80mm with a 90º fold of 50mm x 50mm
* Marking point
* Hammer 

#### How to do it?

We use the work table with a wooden block that holds the metal plate to mark it, supporting the template to make the perforations on it.

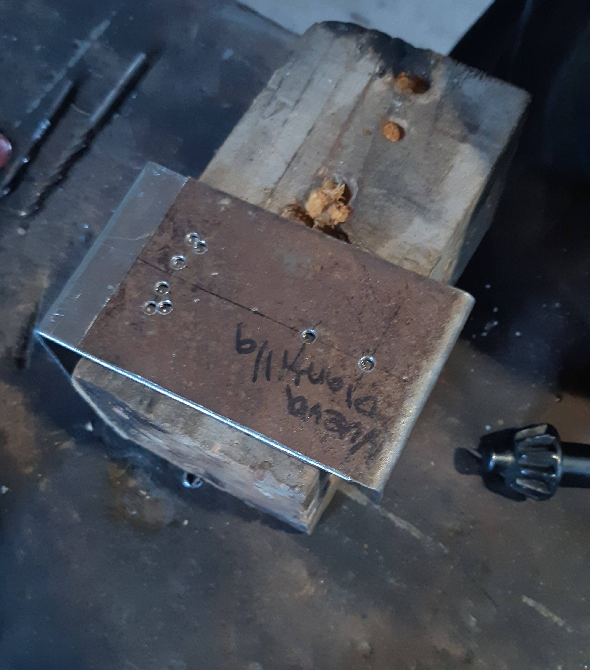
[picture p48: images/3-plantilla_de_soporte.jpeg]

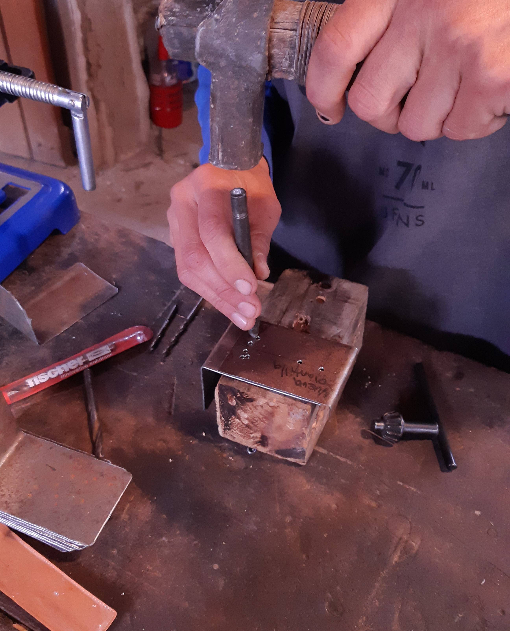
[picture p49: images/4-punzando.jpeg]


With the help of the template we proceed to mark the plate with a marking point and hammer.

If you do not have the resources to create such a template, please visit the following <a href="https://github.com/TecnologiadeRaiz/LoPALiR/blob/main/Marking%20supports.pdf">link.</a>

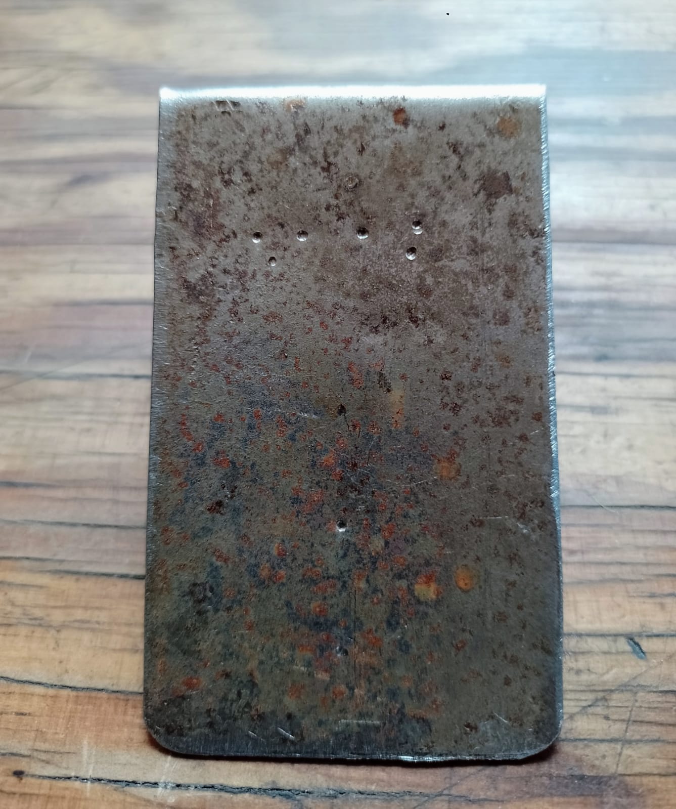
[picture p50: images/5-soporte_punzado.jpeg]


#### Recommendations:

To avoid problems with the alignment of the antennas it is necessary that the template is aligned with the bracket.

## Drilling of metal brackets

#### Workspace:

We use the central work table with the bench drill, and the template designed for this purpose.

#### For this process we need:  

* 6mm wick
* Round and flat file (to remove burrs)
* Bench drill
* Bench vise

#### How to do it?

With the metal plates marked, we proceed to drill them with the bench drill.
Once the holes have been drilled, we file off the burrs.

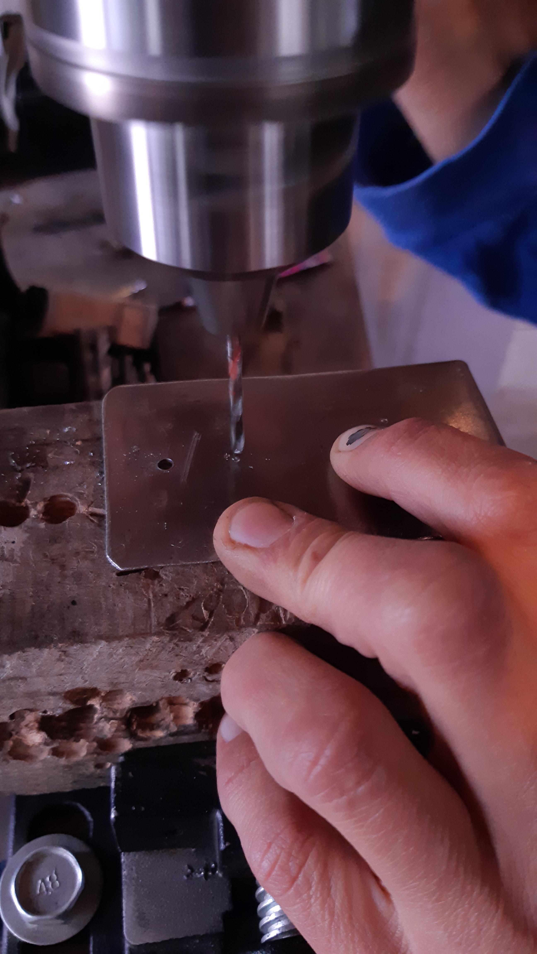
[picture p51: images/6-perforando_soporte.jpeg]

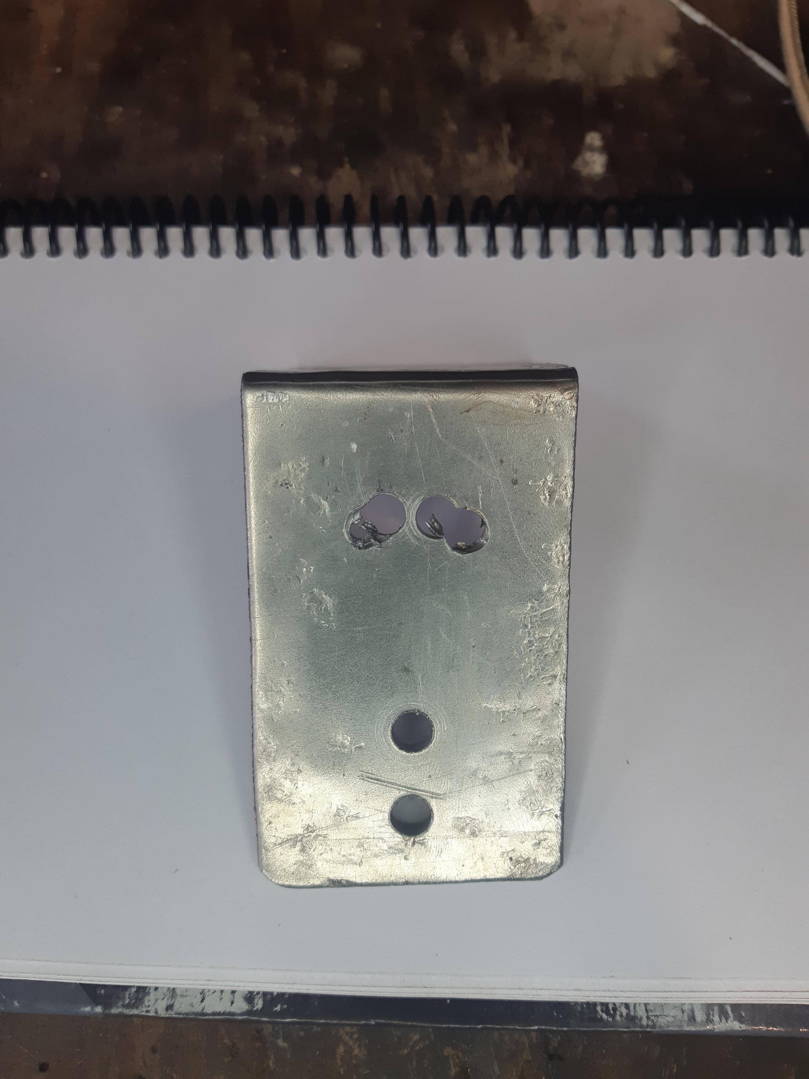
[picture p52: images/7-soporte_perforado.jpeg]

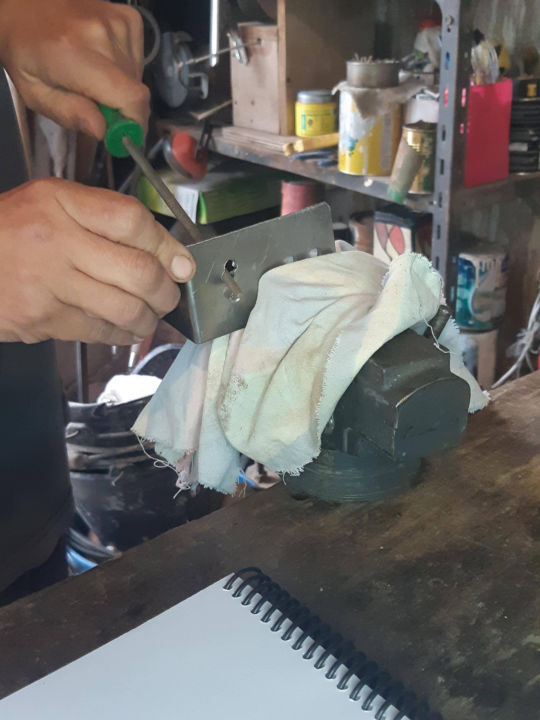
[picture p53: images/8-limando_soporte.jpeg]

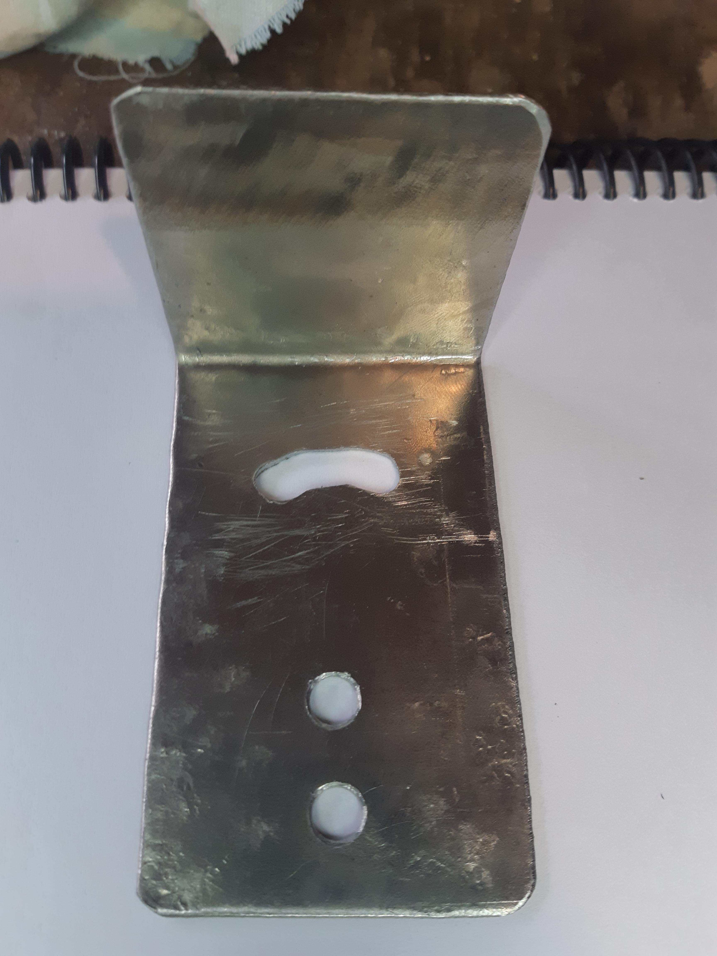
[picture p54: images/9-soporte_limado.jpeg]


#### Recommendations:

It is advisable to use a wooden dowel that the drill bit can hold and allow the metal bracket to rest on it for drilling.
    
It is also advisable not to take too long when drilling to avoid damaging the drill bit, as it gets very hot due to friction. It is also recommended to use low speed when drilling metals.
    
If a bench drill is not available, the brackets can be drilled with a hand drill.

Drilling and tinning of the waveguide

#### Workspace:

For this task, we use the central workbench, with the bench drill.

#### For this process we need:   

* Bench drill
* Induction welder
* Tin

#### How to do it?

With the 130mm iron pipe we proceed to prepare the workbench to drill the waveguide.

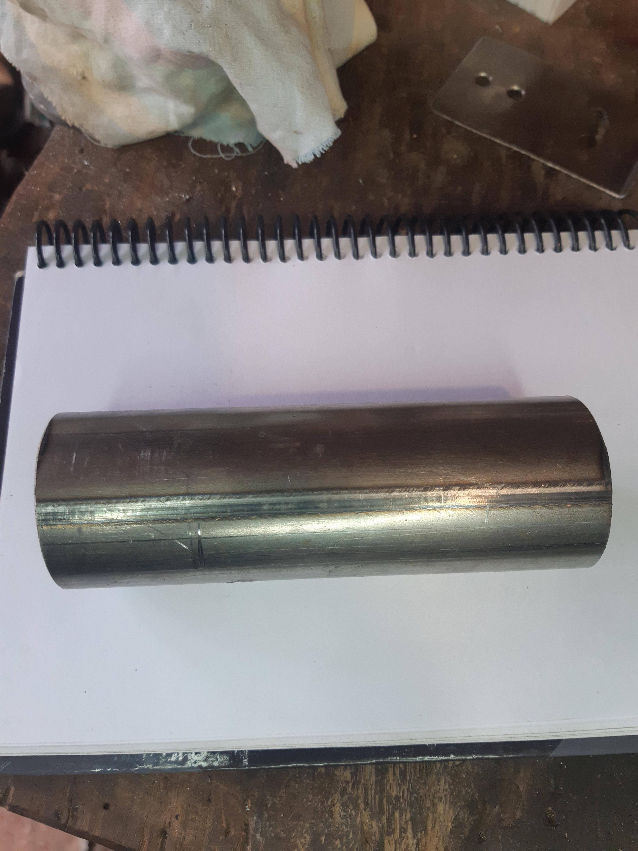
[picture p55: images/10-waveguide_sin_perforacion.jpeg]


With the help of the <a href="https://github.com/TecnologiadeRaiz/LoPALiR/blob/main/MOLDE%20DE%20PERFORACION%20GUIA%20DE%20ONDAS-v2.FCStd">drilling mold.</a>. 

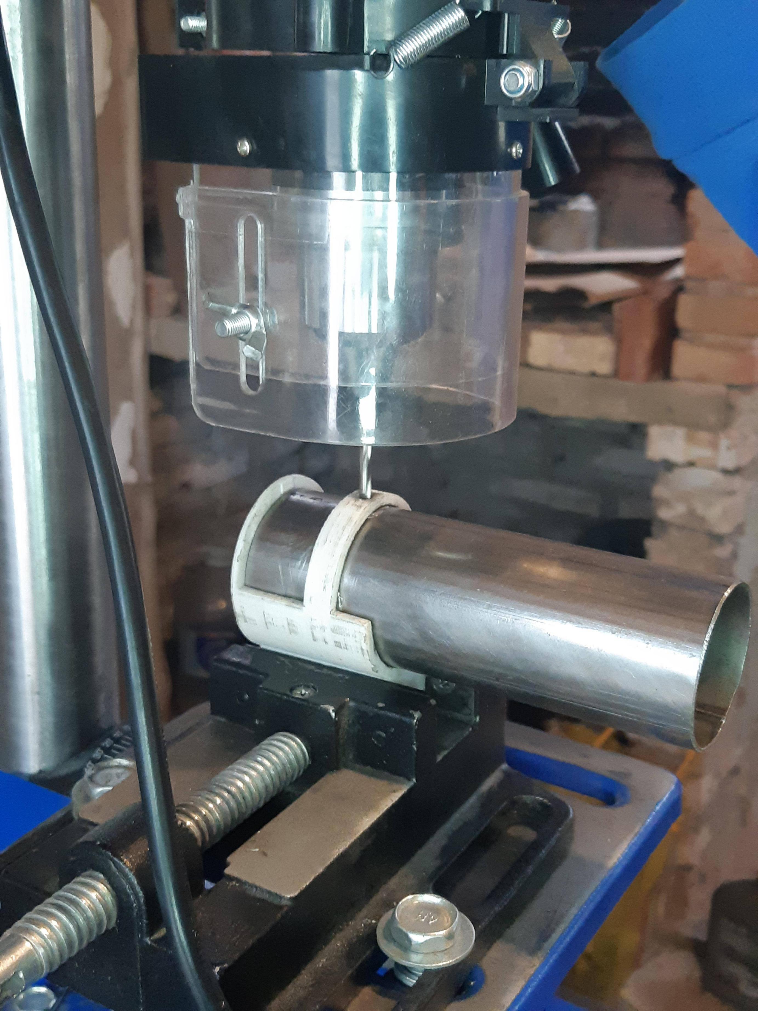
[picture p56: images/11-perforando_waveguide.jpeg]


Once the pipe is drilled we tin around the holes.

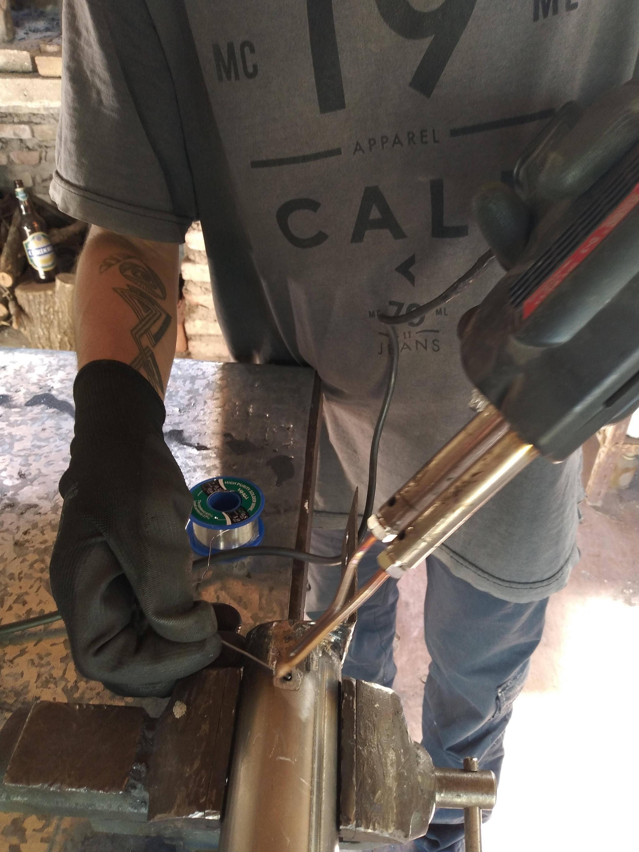
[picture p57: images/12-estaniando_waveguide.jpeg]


If you do not have these tools, you can perform the procedure with other more basic tools. To find out how, visit the following <a href="https://github.com/TecnologiadeRaiz/LoPALiR/blob/main/Drilling%20and%20tinning%20of%20waveguide%20holes.pdf">link</a>

#### Recommendations:

It is important that the holes in the waveguide are aligned with the holes in the bracket, as this will affect the alignment of the antenna.

## Trimming edges to give circular shape to the metal bracket

#### Workspace:

We use the central table of the workspace.

#### For this process we need:  

* Veneer cutter
* Lime

#### How to do it?

The waveguide pipe is used as a template to mark the brackets.
Then with the sheet metal cutter, following the marks, the rounded shape is given.

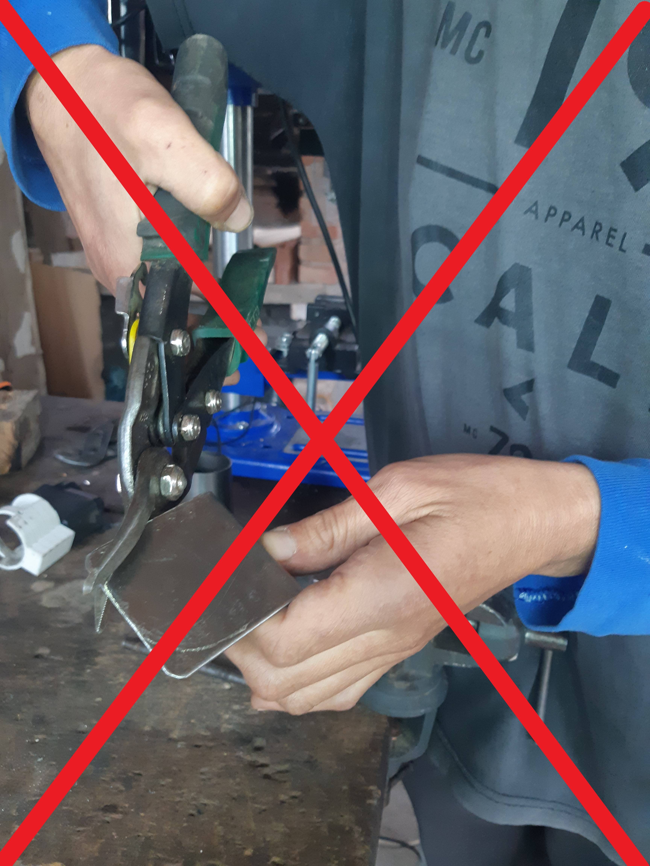
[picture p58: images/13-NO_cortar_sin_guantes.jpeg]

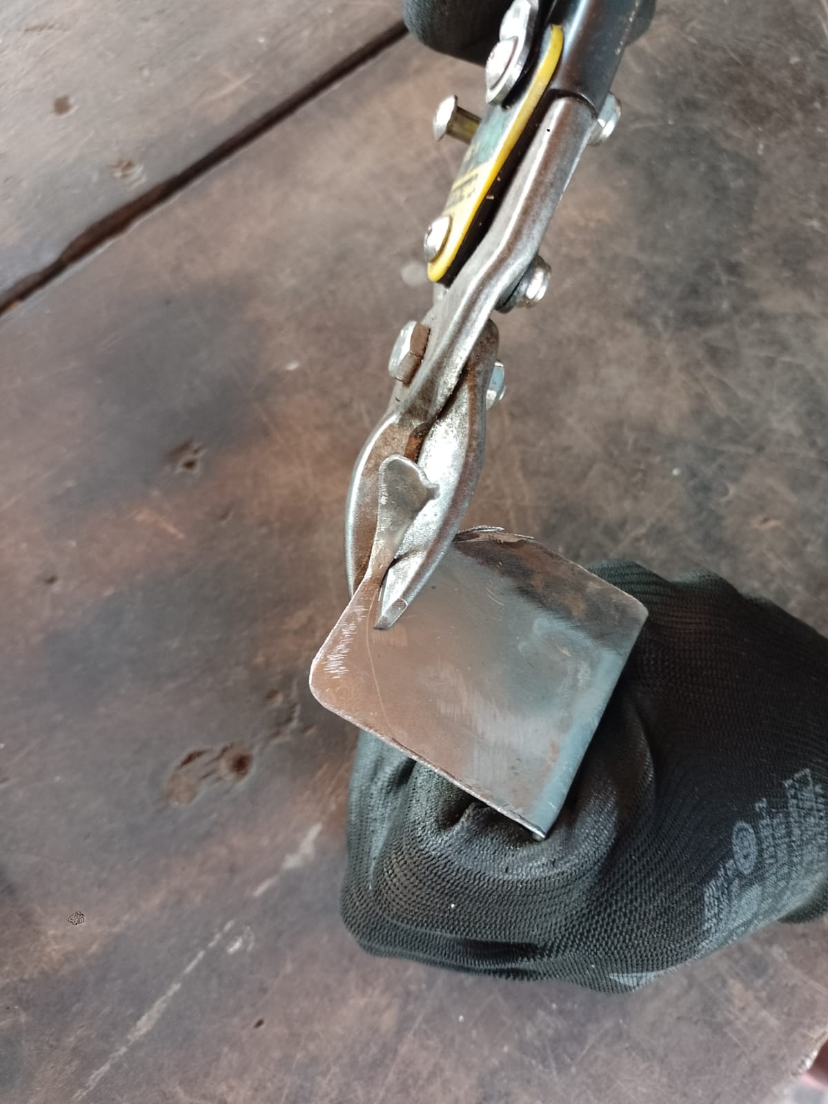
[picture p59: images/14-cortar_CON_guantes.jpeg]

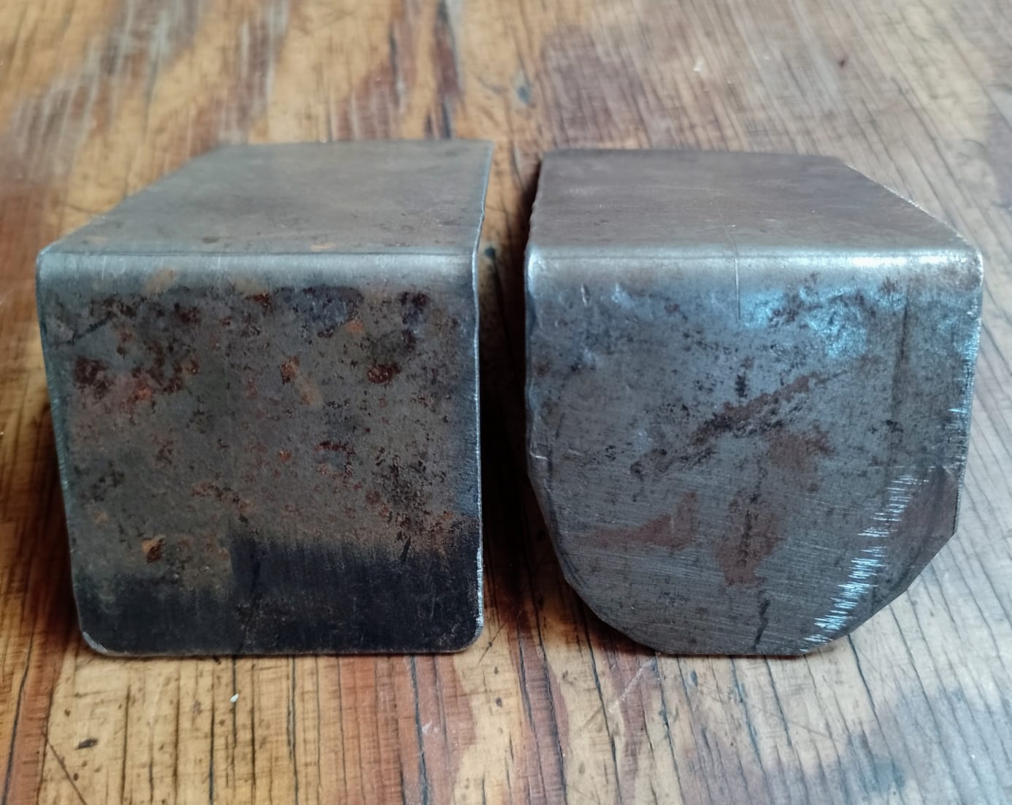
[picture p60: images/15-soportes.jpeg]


#### Recommendations:

Use personal safety elements, in this case gloves.

## Welding brackets

#### Workspace:

We use the work table, with a plate to protect the table from sparks falling during welding.

#### For this process we need:  

* Sheet metal
* Inverter welder
* Electrodes E-6013 (or compatible)
* Bench vise
* Pipe and bracket
* Welding or leather gloves
* Protective mask

#### How to do it?

With the bracket clamped to the mortise by its perforated side, we place the waveguide with the perforations facing downwards and one of them facing the rounded side of the bracket.

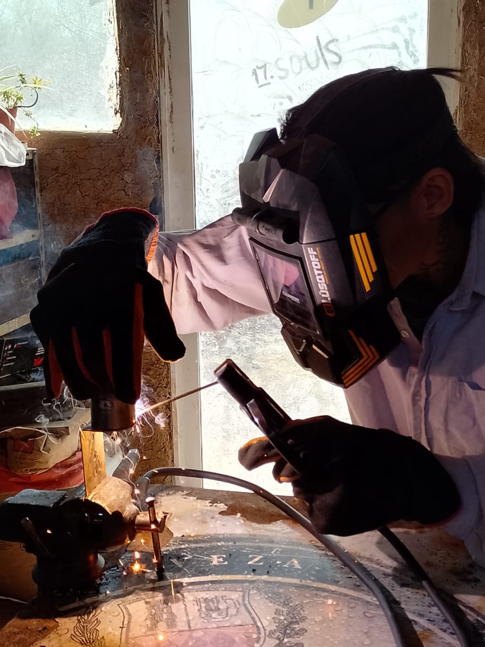
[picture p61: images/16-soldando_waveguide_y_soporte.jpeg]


#### Recommendations:

It is very important to use eye protection, the masks used must be appropriate for electric welders.

## Grinding and puttying

#### Workspace:

We use the central table of the workshop with the bench vise in place.

#### For this process we need:  

* Bench vise
* Grinder
* Grinding disc
* Waveguide with welded brackets

#### How to do it?

Holding the waveguide firmly with the clamp, we remove the excess solder from the bracket and the waveguide.

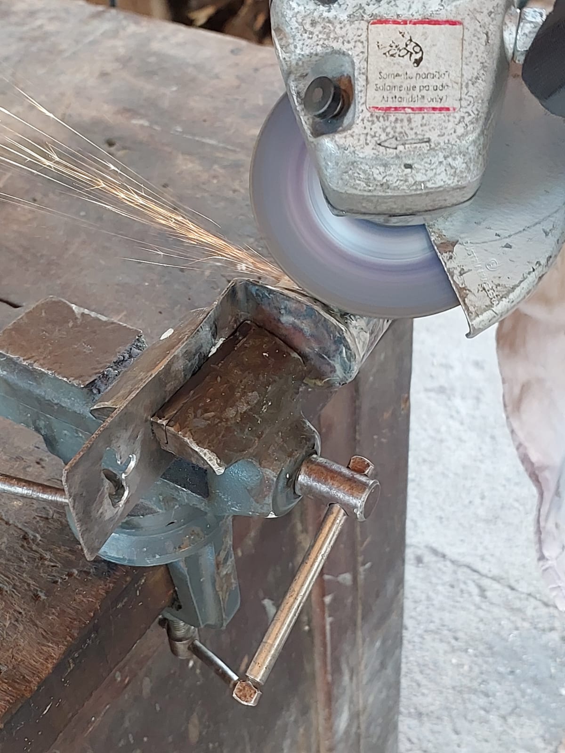
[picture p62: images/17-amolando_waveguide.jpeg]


#### Cautions:

Use personal protection elements, in this case glasses, gloves, hearing protection and work clothes that cover the whole body, so that the metal shavings do not harm us. Also, work with the corresponding ventilation.

## Antenna painting

#### Workspace:

The painting machine is used in a spray booth or outdoors, since the working space inside the workspace is very small, and the machine sprays a large amount of paint.

#### For this process we need:   

* High resistance synthetic paint.
* Painting machine.
* Diluent.

#### How to do it?

To use the machine for painting, the paint must first be diluted so that it is sufficiently liquid to be sprayed by the machine.
For drying, we use a hanging device where they can remain for the necessary time, without hindering the work in the rest of the workshop, until the drying process is finished.

In case you do not have a painting machine, this procedure can be done with a brush.

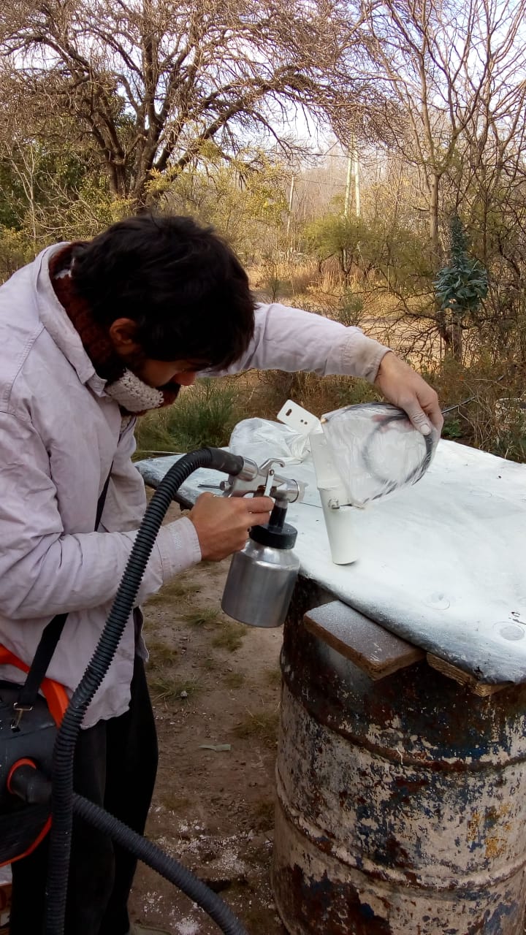
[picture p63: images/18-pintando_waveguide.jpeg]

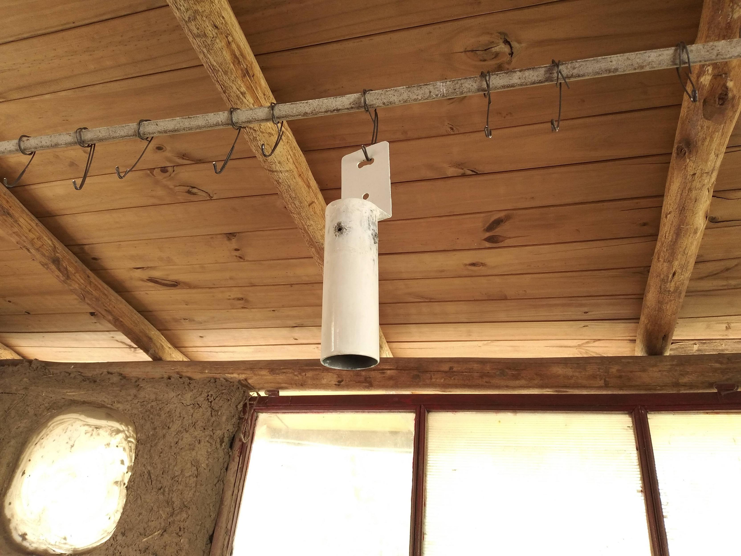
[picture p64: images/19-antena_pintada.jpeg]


## Pigtail cable assembly

#### Workspace:

This part of the production is carried out on a table free of metal filings or shavings.

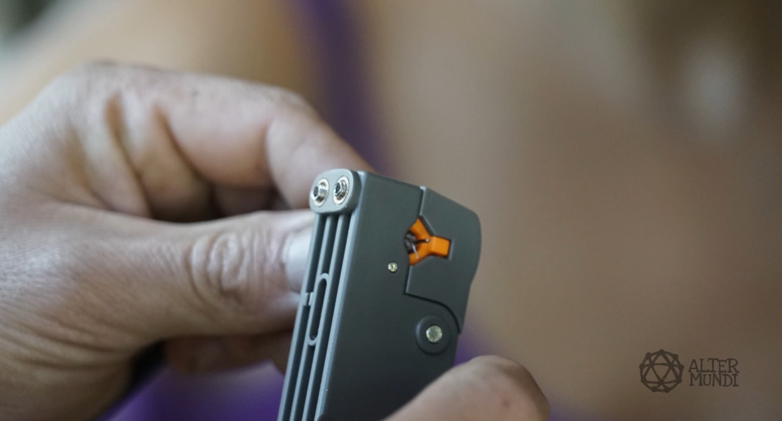
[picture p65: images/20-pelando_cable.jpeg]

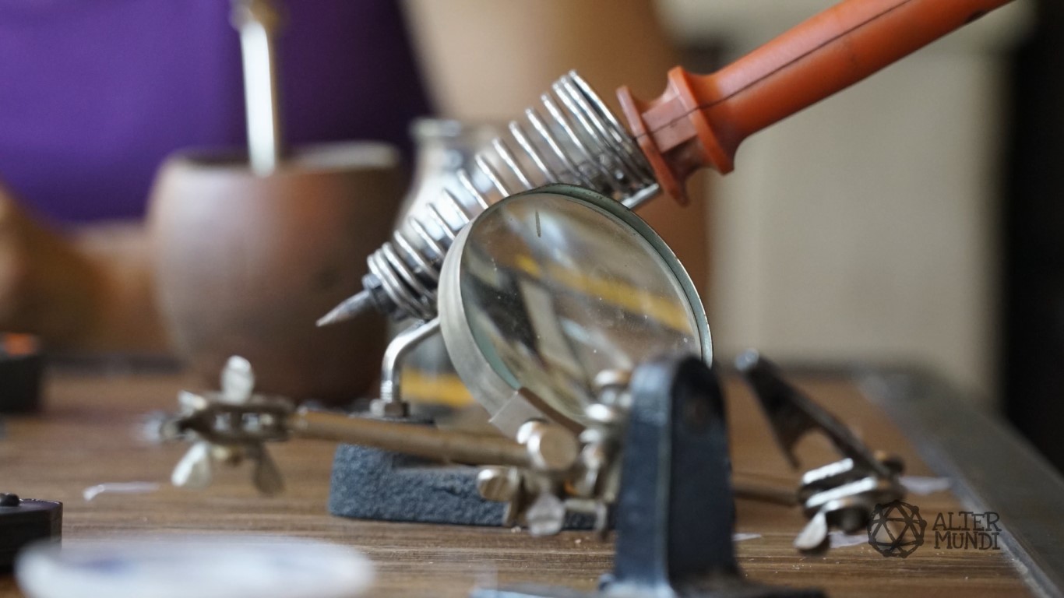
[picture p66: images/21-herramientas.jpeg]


We fit the SMA RP male connectors

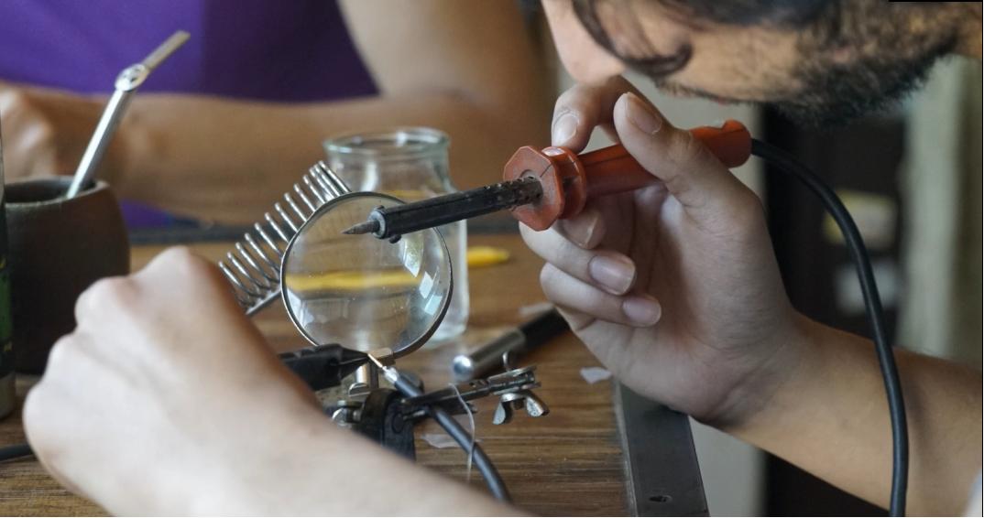
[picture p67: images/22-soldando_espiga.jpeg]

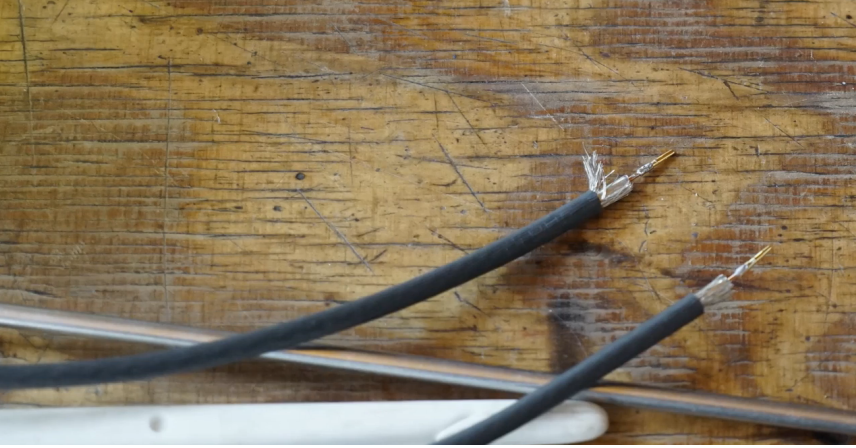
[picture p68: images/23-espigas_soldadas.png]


To show how the process works, we share these explainer videos:

* <a href="https://player.vimeo.com/video/780569067?h=7d256afc33">Assembly part 1</a>

* <a href="https://player.vimeo.com/video/780568264?h=076a3a0531">Assembly part 2</a>

To complete the process, they are crimped and heat-shrunk. 

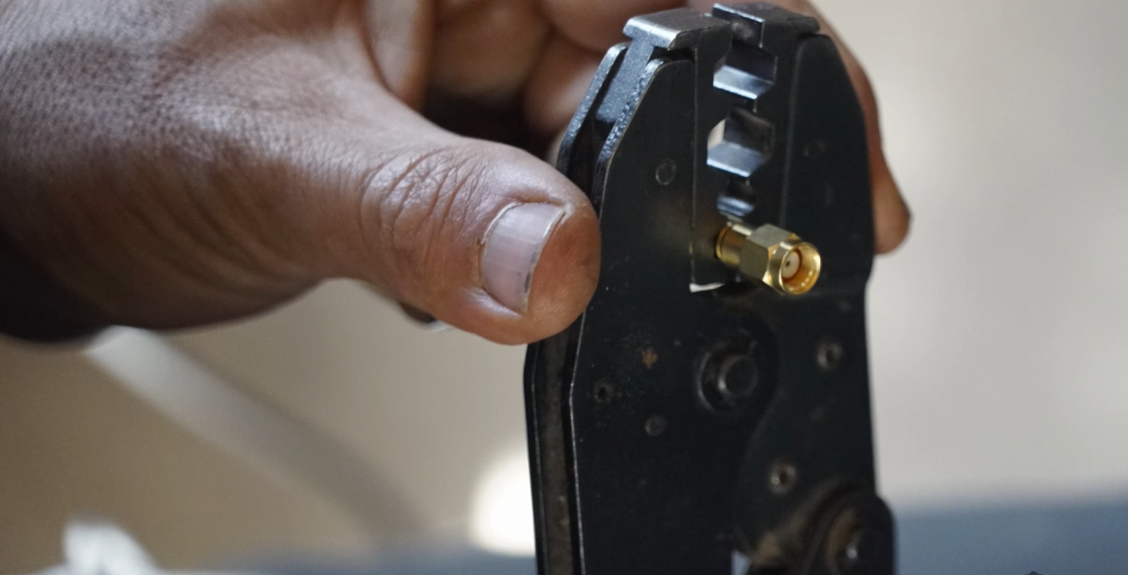
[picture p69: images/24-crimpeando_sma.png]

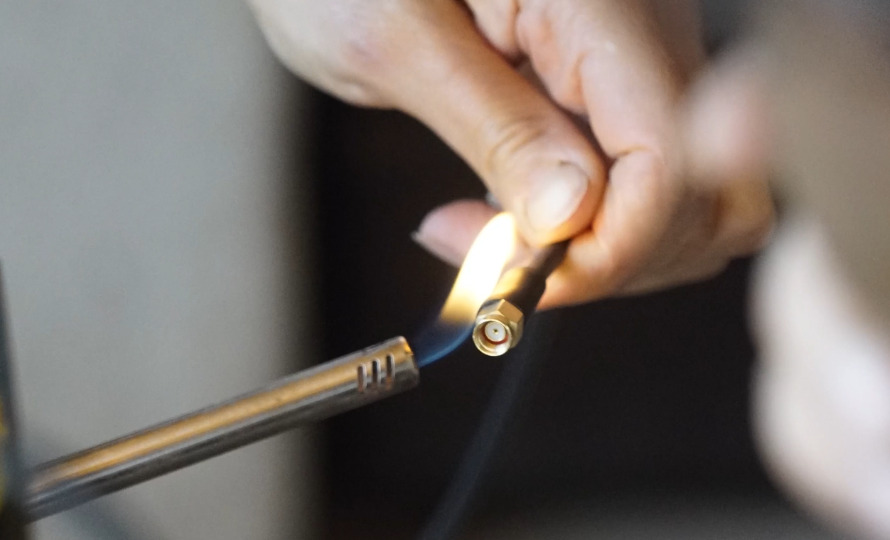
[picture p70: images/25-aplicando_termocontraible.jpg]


At the other end of the wire, we strip the sheath to obtain the pin that will illuminate the waveguide.
We recommend an 11.7mm long pin.



## Solder wires to the pipe

#### Workspace:

This process can be performed on the auxiliary workbench, where we have installed a device with slots to hold the cables. 

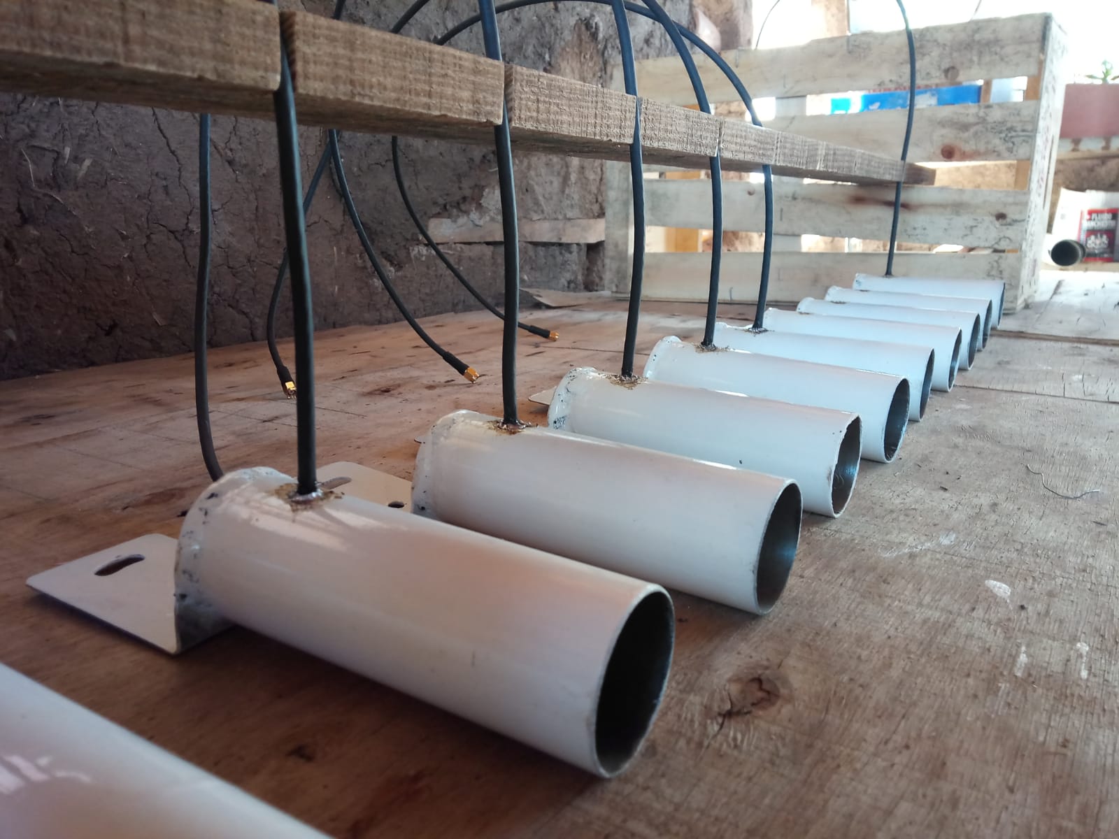
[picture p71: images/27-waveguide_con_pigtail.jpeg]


#### For this process we need:  

* Tin
* Vesuvius welder
* 5mm (3/8") segment of 8mm (3/8") aluminum pipe
* Pigtail cable x2

#### How to do it?

We tin the perforations previously brushed, then we take the pigtail cable, place it in the perforation and solder the mesh to the pipe (waveguide).

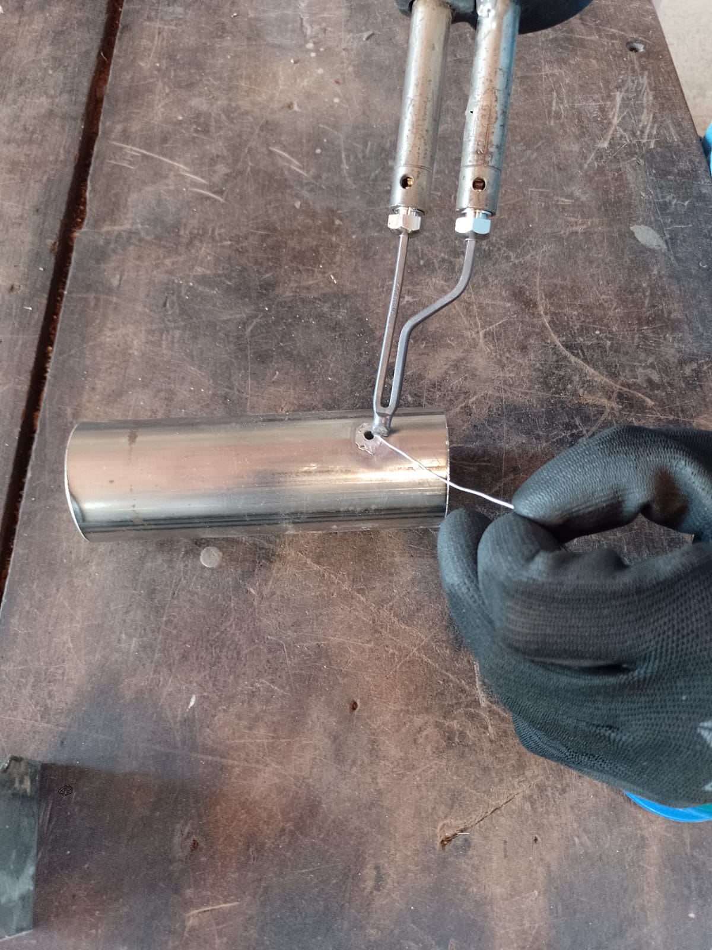
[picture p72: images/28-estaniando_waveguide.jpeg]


>* If you do not have a Vesuvius welder, this work can be carried out with a Zinguero welder.

#### Recommendations:

We must make sure that the soldering iron is very hot and clean, in order to minimize the contact time and thus not burn the cable sheath.

## Portachains rings printing

#### Workspace:

We use a piece of furniture where the 3D printer is positioned, sheltered from the hostility of the workshop.

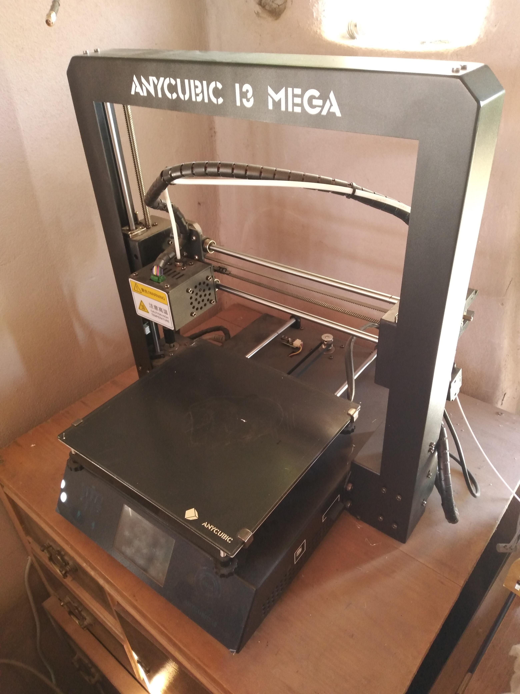
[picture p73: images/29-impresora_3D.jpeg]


#### For this process we need: 

* Designs made in Freecad

* 3D Printer

* Petg Filament

#### How to do it?  

We laminate the designs (.stl) made in Freecad to obtain them in .gcode format in this case, we store them in a memory card that we insert in the 3D printer to print them.

## Fitting portachains rings

#### Workspace:

We use the auxiliary table to place the portachain.

#### For this process we need: 

* Portachain rings   

* Antenna with welded cables

* 3/8" aluminum pipe

#### How to do it?

The larger ring is inserted through the waveguide, until it reaches the place where the cable is located.
Then attach the rear carrier, using a 5mm segment of 3/8" aluminum pipe, passing it through the cable and bringing it up to the two carriers together, and crimping it to hold the cables securely.

## Testing

#### Workspace:

This work can be performed on the device created to hold the cables.

#### For this process we need: 

* <a href="https://github.com/TecnologiadeRaiz/LoPALiR/blob/main/About%20RC%20Antenna%20SWR%20Meter.pdf">RC Antenna SWR Meter.</a>

#### How to do it?

First of all, an visual inspection is carried out in order to arrange the two pins at 90 degrees.
Once this procedure is done, one of the wires is connected to the RC antenna meter and the waves emitted by that chain are measured first, and then those of the other one.

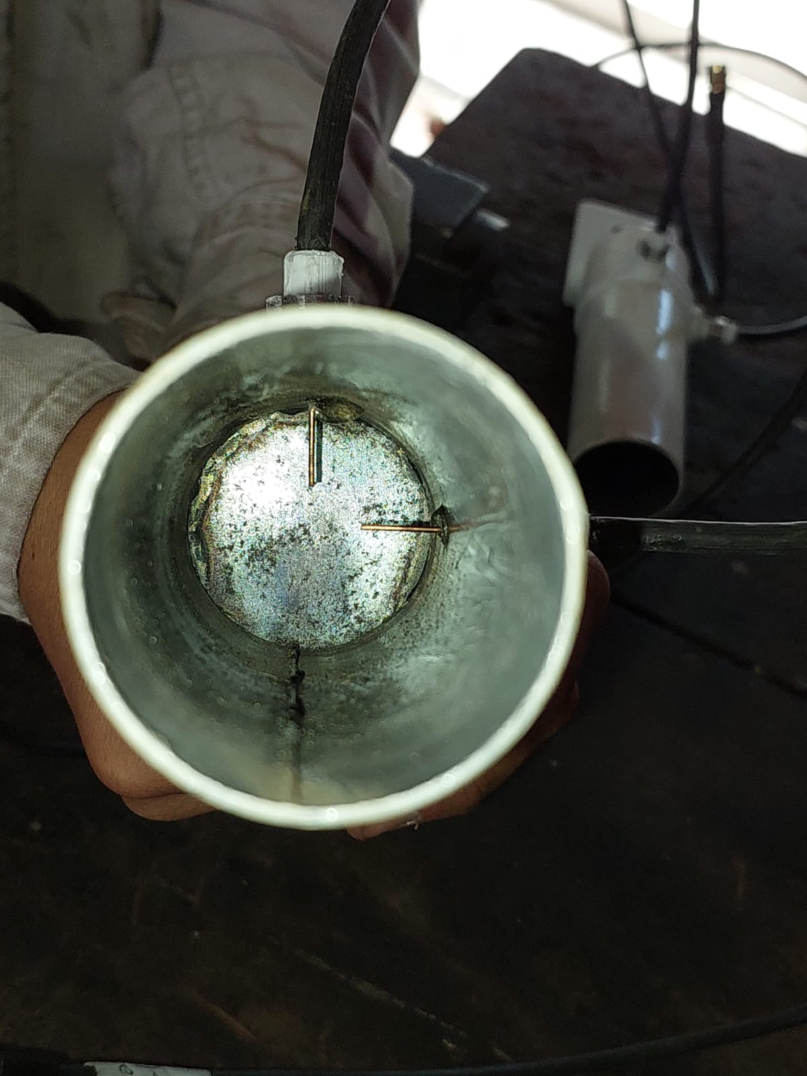
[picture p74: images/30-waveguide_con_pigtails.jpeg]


## Placing covers and finishing

#### For this process we need: 

* Plastic lid 

* Assembled waveguide

To protect the illuminators, the waveguide is closed with a plastic cover and silicone sealant to prevent leaks.

## Finished antenna    



>!TDR is not responsible for possible damages caused by performing these procedures using this informative material.

___

Logo NLnet: abstract logo of four people seen from above

<p>This project was funded through the <strong> <a href="https://nlnet.nl/useroperated/">User-Operated Internet</a> </strong> fund, a fund established by <a href="https://nlnet.nl">NLnet</a> made possible by financial support from the <a href="https://pkt.cash" rel="nofollow">PKT Community</a> <a href="https://pkt.cash/network-steward" rel="nofollow">The Network Steward</a> and stichting <a href="https://technologycommons.org">Technology Commons Trust</a>.</p> 

<p>Saludamos a les amigues de <a href="https://altermundi.net/">AlterMundi.</a></p>

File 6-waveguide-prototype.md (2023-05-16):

<!--
SPDX-FileCopyrightText: 2023 Tecnología de Raíz <tecnologiaderaiz@disroot.org>

SPDX-License-Identifier: CC-BY-NC-4.0
-->

# Prototyping

<p>
  
We will describe some characteristics of each antenna, and a graph of their tests performed with a <a href="https://github.com/TecnologiadeRaiz/LoPALiR/tree/main/Mediciones">program</a> specially designed equipment for this purpose in a distance of 1.1 km.

Our test scenario is located between a very tall pine tree in the town of Casa Grande and the top of a house in the town of Molinari.
</p>

<br>


<h2>
    <u>
        Prototype 1
    </u>
</h2>

<h3>
    Version 1:
</h3>

<p>
In the search for a waveguide type antenna, we developed this prototype; one of the aspects we worked on is the creation of a support for the antenna and the assembly of the cables on the waveguide.
</p>

<p>
<b>
   An early attempt at support was this:
</b>
</p> 



<p>
<b>
  Taking an existing support, we welded the waveguide to it.
</b>
 In this case we use a 38mm diameter pipe.
</p>

<br>

<ul>
    <li>
        Advantages:
    </li>
</ul> 

<p>
The way to hold the cables in this prototype was to make a groove in the waveguide and with that material, adding a copper pipe, hold the cable. This simplifies the assembly.
</p>
    
<ul>
    <li>
        Disadvantages:
    </li>
</ul>

<p>
Due to the characteristics of the material, its weight and its shape, we found this support design not very functional; this led us to rethink how to use the material and the shape of the support.

The slot generates radiation loss.

The diameter of the pipe "cuts" the passage of lower frequencies.
</p>



<hr>

<h3>
    Version 2:
</h3>

<p>
<b>
   We tried modifying the length of the waveguide, with a longer pipe.
</b>
</p>



<p>
   In this version, we modified the way of fastening the cables by soldering a copper pipe to the waveguide, crimping it, and sealing it with heat shrink.
</p>

<ul>
    <li>
        Advantages:
	</li>
</ul>

<p>
   Robustness in the grip precision in the final position of the illuminators.
</p>

<ul>
    <li>
        Disadvantages:
    </li>
</ul>

<p>
   We use an autogenous welder (oxygen and acetylene) which incre

ases the complexity of the workshop and the difficulty of welding.

There is also the possibility of generating "joint stresses" between the materials, which could affect the performance of the antenna.
    
</p>



<h2>
    <u>
       Prototype 2 Conical:
    </u>
</h2>

<h3>
    Version 1:
</h3>

<p>
    <b>
        In this version, we reattached the cables as in the previous version, soldering a copper pipe to the waveguide, crimping it, and sealing it with heat shrink.
    </b>
   
</p>



<ul>
    <li>
        Advantages:
    </li>
</ul>
<p>
    We observed that the addition of the conical supplement improves its performance.
</p>

<ul>
    <li>
        Disadvantages:
    </li>
</ul>
<p>
    For this prototype, we used the large bracket, which is very heavy. We consider it not very functional.
</p>



<h3>
    Version 2:
</h3>

<p>
   <b>
       In this prototype, we shortened the length of the pipe, with an internal diameter of 42 mm, adding a conical end made of sheet metal and welded.
</b>
 
To support the cables, we designed a "bridge" type grip with sheet metal welded to the waveguide. 
</p>




<ul>
    <li>
        Advantages:
    </li>
</ul> 
<p>

   In relation to the support, being lighter and more compact, it allows to move it more easily, being also more economical because it has less material.
    
In this version of the support, we drilled holes to take advantage of the measures of the "threaded u" that are easily available in hardware stores, creating a support adaptable to two sizes of pipe. This provides accessibility to the product.
    
</p>
<p>
   With this design, we are using the bracket as the waveguide cover. The first prototype of the bracket welded as the antenna cover was 10 cm long. 

Then we chose to leave room for only two sizes of "threaded u", thus giving the possibility to complete the bracket according to the pipe where it is attached.
</p>

<ul>
    <li>
        Disadvantages:
    </li>
</ul> 

<p>
   In this prototype, we found many difficulties in soldering the wires to the waveguide. It can be seen in the measurement graph as chain 2 (the green one) with failures in the soldering of the mesh, has lower gain.
</p>





<h2>
    <u>
       Prototype 3
    </u>
</h2>

<p>
    <b>
        In this version, we retested attaching the wires with the bent sheet metal "bridge" model, on a shorter waveguide prototype, with 44mm internal diameter, without a cone.
    </b>
   
</p>




<p>
   Although we obtained very good results in antenna performance, we are still looking for a simpler way to attach the wires, preserving the length of the waveguide in the next prototype.
</p>



<ul>
    <li>
        Advantages:
    </li>
</ul>
<p>
    We obtained good performance results.
</p>
<ul>
    <li>
        Disadvantages:
    </li>
</ul>
<p>
   Difficulty in soldering the wire mesh to the pipe 
</p>

<h2>
    <u>
       Prototype 4 Resin
    </u>
</h2>

<p>
    <b>
        In this prototype, we tested attaching the cables with a ø=1/8 inch hose, transparent, filled with epoxy resin. 
    </b>
 
</p>



<ul>
    <li>
        Advantages:
    </li>
</ul>
<p>
    Antenna performance results were good.
    
</p>

<ul>
    <li>
        Disadvantages:
    </li>
</ul>

<p>
   Fragility at the junction of the cables with the waveguide. Some tests came unglued, making them unusable.
    
Difficulty in removing resin residues in case of need for repair.
    
Toxicity of the process and the resulting residues.
</p>



<h2>
    <u>
       Prototype 5 Coupling of plastic parts
    </u>
</h2>

<p>
    <b>
        Through the <a href="https://github.com/TecnologiadeRaiz/LoPALiR/tree/main/Partes%20plasticas">design</a> in <a href="https://www.freecadweb.org/">Freecad</a>, we were able to 3d print plastic parts that allow, by coupling, to hold the cables in an efficient, fast and durable way.
    </b>
    
</p>




<ul>
    <li>
        Advantages:
    </li>
</ul>

<p>
   Simple assembly.
    
Robustness and precision in cable gripping.
</p>

<ul>
    <li>
        Disadvantages:
    </li>
</ul>

<p>
   Access to 3D printing.
    
Need to develop waterproofing at the junction of the plastic parts.
</p>

Logo NLnet: abstract logo of four people seen from above

<p>This project was funded through the <strong> <a href="https://nlnet.nl/useroperated/">User-Operated Internet</a> </strong> fund, a fund established by <a href="https://nlnet.nl">NLnet</a> made possible by financial support from the <a href="https://pkt.cash" rel="nofollow">PKT Community</a> <a href="https://pkt.cash/network-steward" rel="nofollow">The Network Steward</a> and stichting <a href="https://technologycommons.org">Technology Commons Trust</a>.</p> 

<p>Saludamos a les amigues de <a href="https://altermundi.net/">AlterMundi.</a></p>

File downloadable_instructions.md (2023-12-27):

<!--
SPDX-FileCopyrightText: 2023 Tecnología de Raíz <tecnologiaderaiz@disroot.org>

SPDX-License-Identifier: CC-BY-NC-4.0
-->

#Manual

Below we share a downloadable PDF instruction manual for greater user accessibility.



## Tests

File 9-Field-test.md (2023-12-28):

<!--
SPDX-FileCopyrightText: 2023 Tecnología de Raíz <tecnologiaderaiz@disroot.org>

SPDX-License-Identifier: CC-BY-NC-4.0
-->

# Field test

## Exploring horizons: antenna testing in diverse environments

In this material we are going to share the experiences in which we worked in relation to the field tests of our antennas, telling about the programes and organizations and referencing those who took part in these processes. We consider these experiences to be very enriching for the groups that took part, as the articulation between organizations allows us to continue growing and learning. It also enables those who require it to deploy, expand and build inputs for community networks. One of these experiences is the ANERA project, in which AlterMundi promoted the participation, training and strengthening of a national programe of grants to community networks [Roberto Arias - ENACOM](https://altermundi.net/2022/11/03/ieee-reconocio-con-el-primer-premio-al-semillero-de-redes-comunitarias-para-postulantes-al-programa-roberto-arias/). In the development of this successful project, several activities were carried out, such as a [face-to-face meeting](https://elbrote.org/alegria-comunidad-y-redes-libre/) in which [we delivered the antennas manufactured in the TdR workshop to several networks throughout the country](https://www.instagram.com/reel/CkwruueuoDV/?igshid=MTc4MmM1YmI2Ng==).

This is also the case in India, where, thanks to the ["Community of Practice"](https://communitynetworks.group/c/cops/16) programe of the "Association for Progressive Communications" and the participation of the community of [Janastu](https://open.janastu.org/projects), exchanges of practices and methods of antenna production took place.

Similarly, the [Colnodo](https://colnodo.apc.org/es/experiencias/el-equipo-de-redes-comunitarias-de-colnodo-fabrica-prototipo-de-antena-para-conectar-territorios-en-colombia) community in Colombia adopted our design and manufacturing method, testing their first prototypes in laboratories at the Universidad Departamental de Bogotá.

Following these experiences and with the aim of carrying out field tests of the conical version of our antennas, we organized a visit to Campo de la Rivera, a popular neighborhood on the outskirts of the capital of Córdoba, where the residents created a community network to solve their connectivity problems, mainly related to the lack of resources to access the expensive services provided by telecommunications companies. There, members of the Encuentro de Organizaciones group installed 5 LibreRouter nodes with antennas built by TdR, which we replaced with conical antennas for field tests. In this part of the neighborhood, the community network and the TdR antennas provide connectivity to neighbors, as well as to a [community space](https://www.facebook.com/asambleadecampodelaribera/) where there is a dining room, a picnic area and other activities that enrich the community work. There, we met in the community kitchen, where we shared activities and they showed us how the network works in order to start the tests.

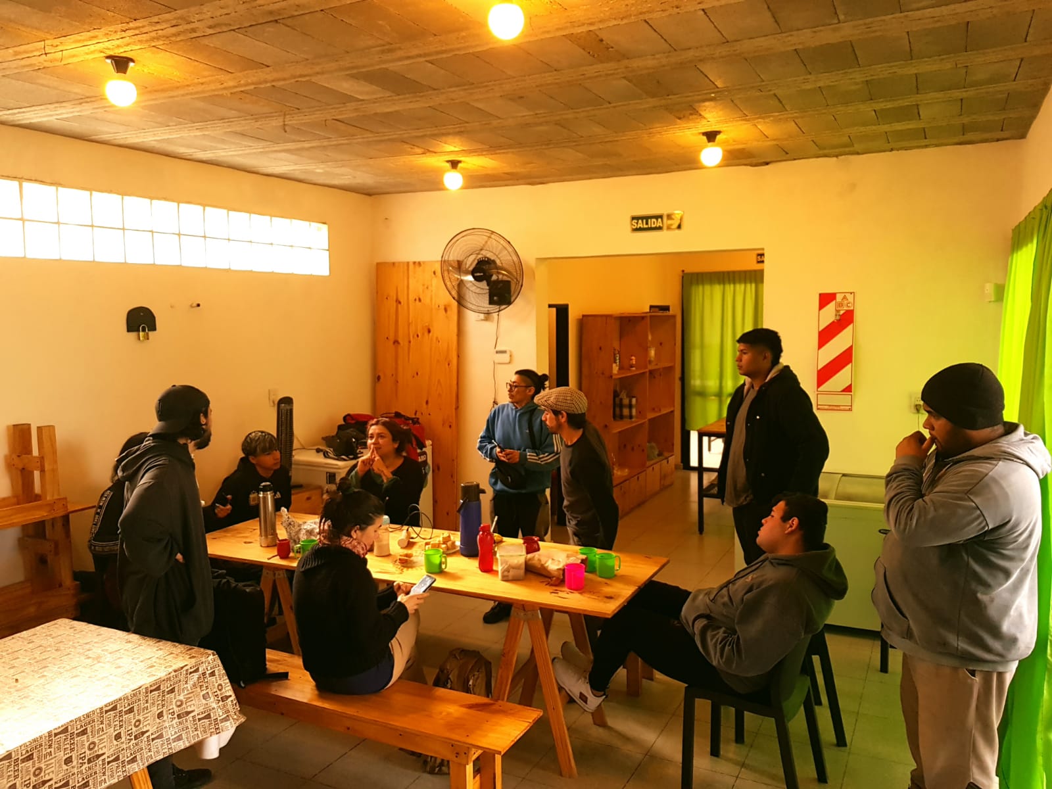
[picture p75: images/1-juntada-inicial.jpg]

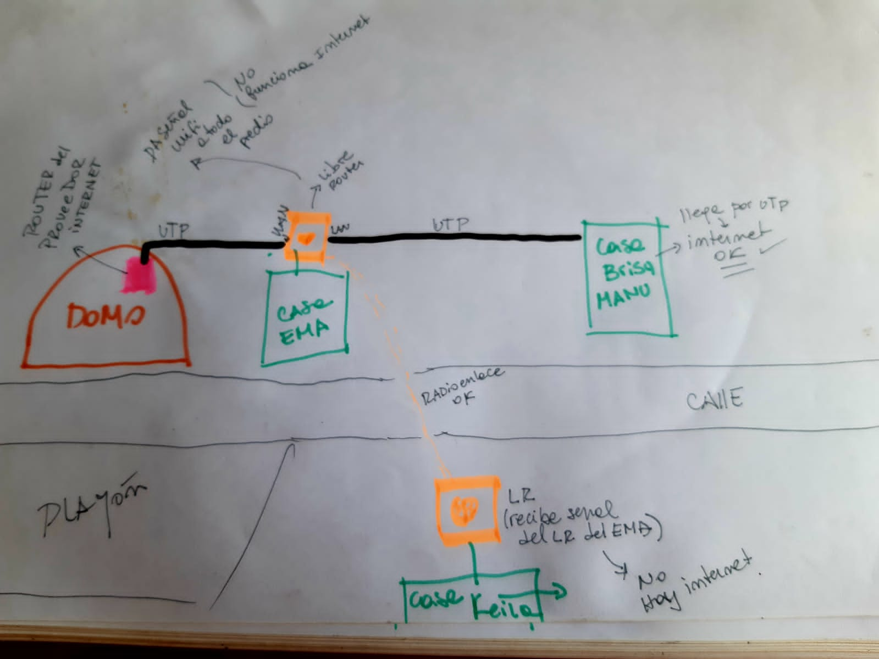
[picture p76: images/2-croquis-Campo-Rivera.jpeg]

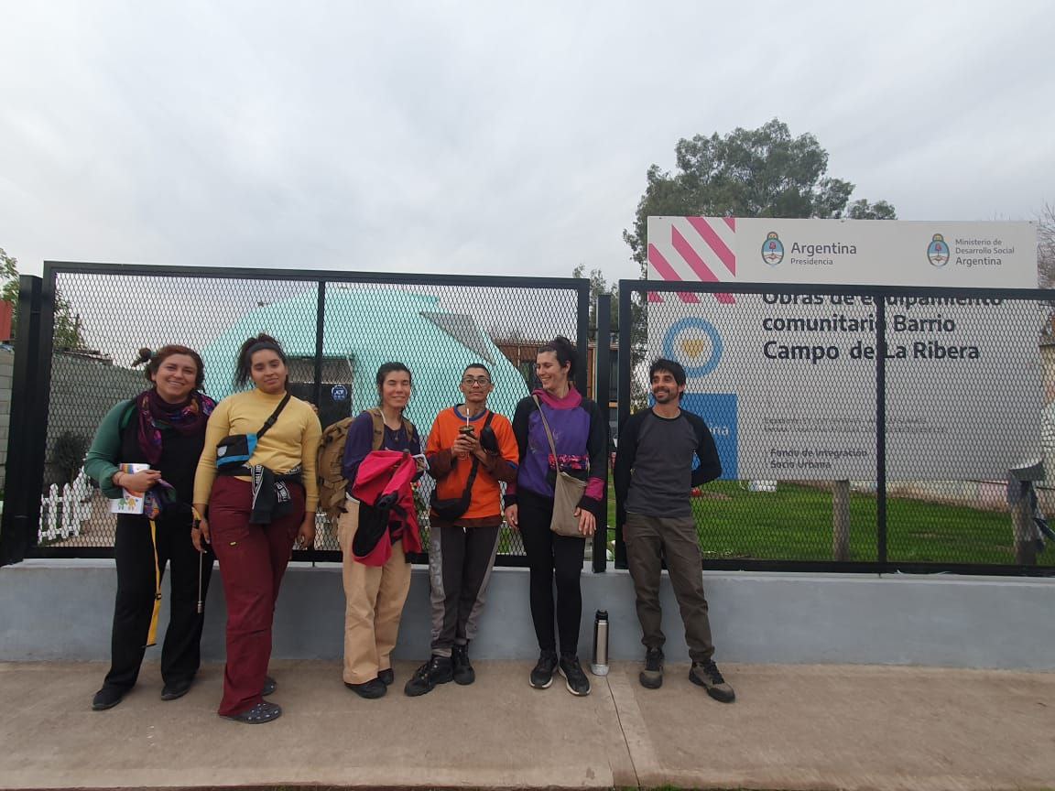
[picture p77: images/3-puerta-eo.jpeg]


---

### Test results

#### "Campo de la Ribera"

First, we carried out measurements with the antennas that were installed in the Campo de la Rivera network. These antennas, carried out with the resin cable clamping method, gave the following results: 

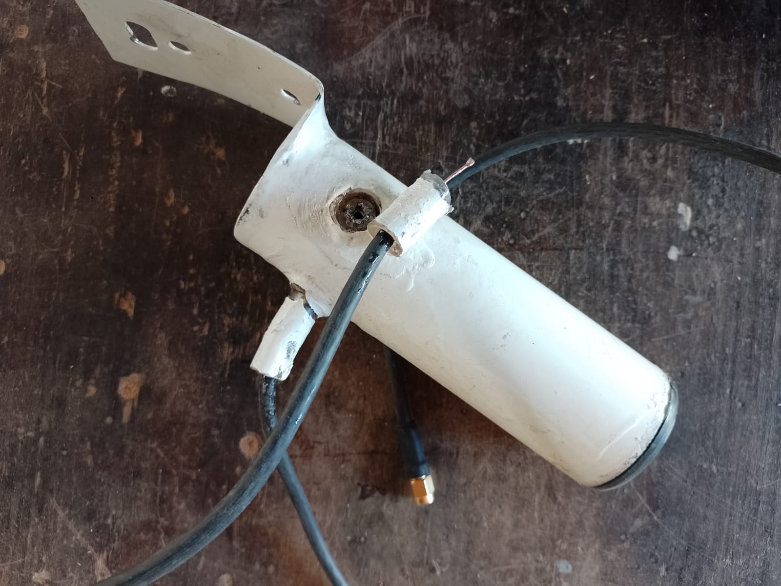
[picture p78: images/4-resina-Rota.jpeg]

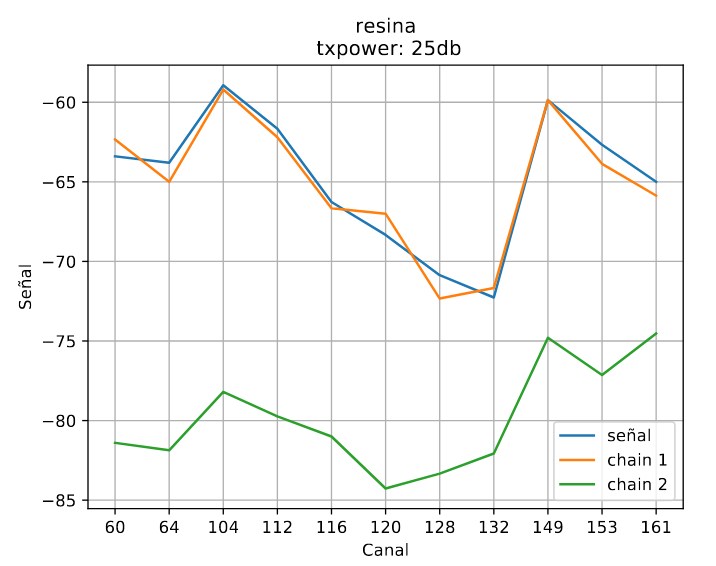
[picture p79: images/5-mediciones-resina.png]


Here we can see how this prototype does not solve the need, as the cables are not firmly attached, which negatively affects the performance of this prototype; the result of this inconvenience can be seen in the image where chain 2 has a lower signal level than chain 1.

After finishing the tests with the resin clamped prototype, we installed a conical version prototype which gave these results:

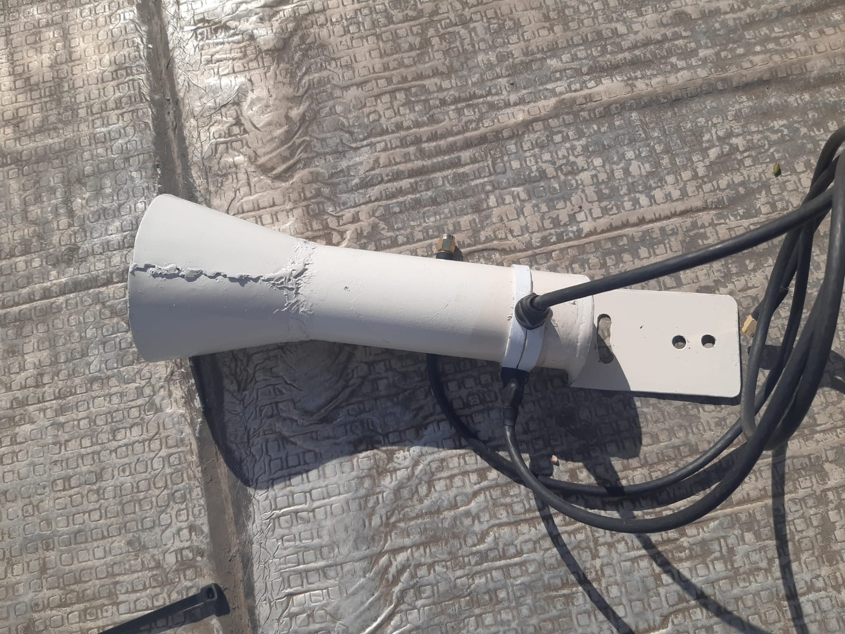
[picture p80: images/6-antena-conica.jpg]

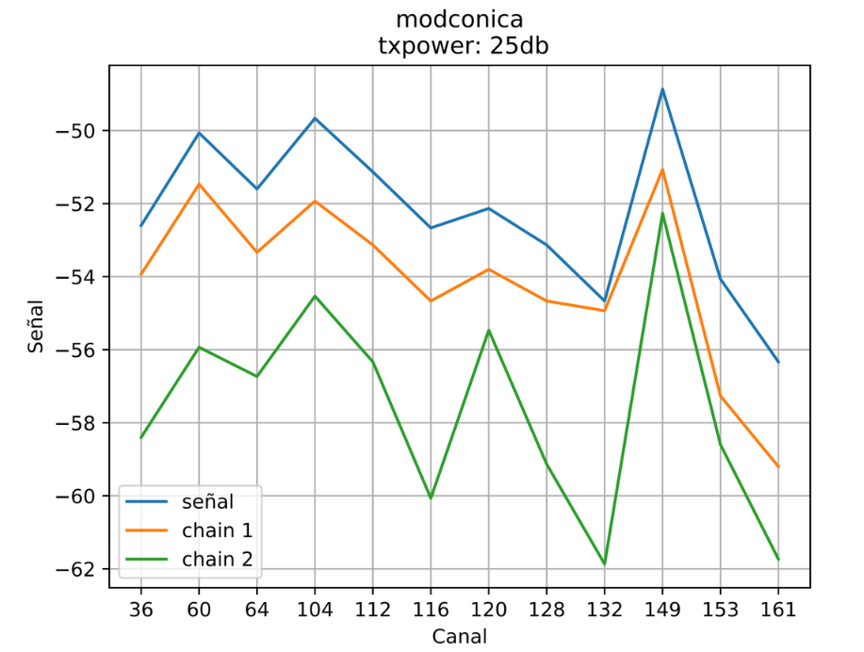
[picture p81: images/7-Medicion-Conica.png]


In this graph we can see that the antenna signal in its chain 1 reaches -54dB in the central channels. It is important to bear in mind that, in the graphs, the signal in dB is reflected vertically and the channels used horizontally. The different signal levels are not located equally in all the graphs shown, so in order to make a comparison between the performance of the different prototypes, we must always pay attention to the reference in dBs contained in each image.

---

#### "El Montecito" y "Casa Grande"

Our next field test was carried out in the community network in our territory. Here [MonteLibre](https://libregrande.online/) allows 60 families from two neighboring villages to access communication.

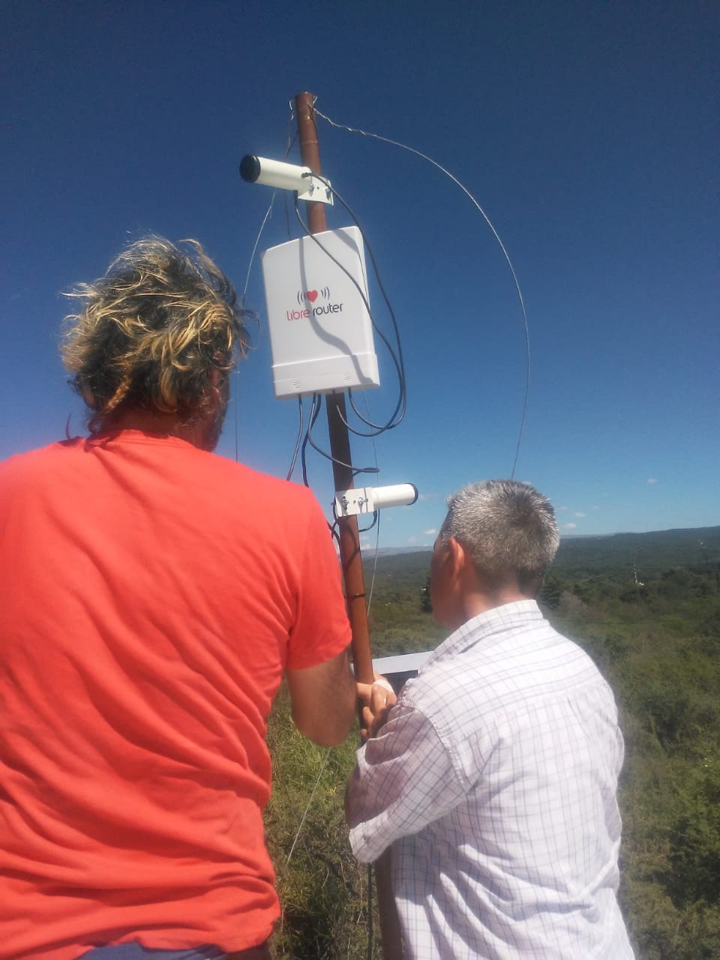
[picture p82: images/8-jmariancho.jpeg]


This network, which already had waveguide antennas built in the TdR workshop, allowed us to carry out field tests between two of its main nodes located at a distance of 1.2 km.

We initially carried out measurements with the version 5 antennas, already installed and operating in the network, which gave these results:

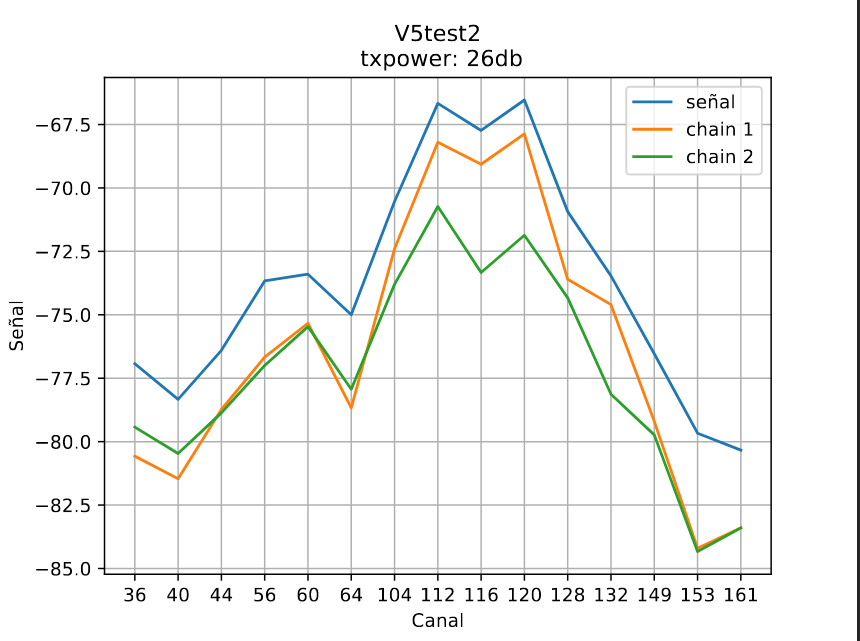
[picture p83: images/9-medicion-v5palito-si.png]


In this test carried out with a power set at 25dB, 8 references are shown in the vertical direction, and a maximum performance of chain 1 at -68dB.

In this same scenario, where we have tested the previous prototypes, we placed the conical version and obtained these results:

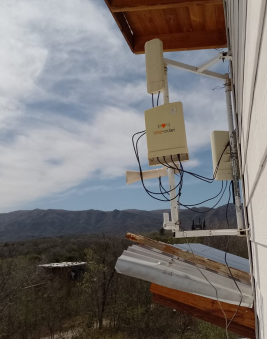
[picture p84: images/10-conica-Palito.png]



In conclusion, we have found that the performance of the conical antennas is very good, and can improve connectivity compared to the other versions, as they provide higher signal gain level using only slightly more material. Although this makes it much harder to build

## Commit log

2023-04-27 agrego gitbuilding.yml para automatizar web
2023-05-03 imagenes en galerías
    [MOLDEDEPERFORACIONGUIADEONDAS-v2.stl]
2023-05-03 armo galeria con los enlaces de fotos
2023-05-04 galerias de fotos
2023-05-04 modificaciones de algunos archivos
2023-05-04 agrego waveguide.stl
    [waveguide-accesorios.stl]
2023-05-09 licenciado de videos
2023-05-16 actualizacion de planos e imagenes
2023-10-02 Creacion de Field test.md y licenciado
